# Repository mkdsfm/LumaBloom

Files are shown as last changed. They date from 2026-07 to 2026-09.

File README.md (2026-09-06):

# LumaBloom

Smart ambient-light sensor for Windows displays with ESP32-C6 and displayless ESP32-C3 Super Mini electronics variants for the same printable flower design.

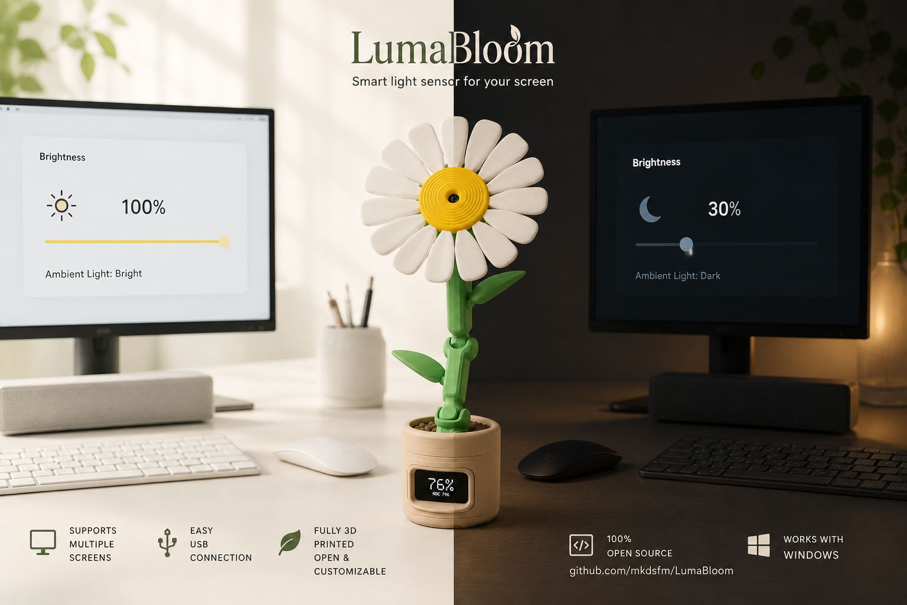
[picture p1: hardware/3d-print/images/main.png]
LumaBloom product preview


[Watch the demo video](https://youtu.be/8JuLW-chpVk?si=8Hq7ECl7L5f6ZxNs)

LumaBloom reads room light from a KY-018 sensor on a supported ESP32 board, streams raw JSON telemetry over USB, and lets the Windows companion app adjust monitor brightness automatically.

## Highlights

- ESP32-C6 firmware for Waveshare `ESP32-C6-LCD-1.47` with an ambient-light-driven pixel-art flower animation.
- Displayless ESP32-C3 Super Mini firmware for a compact `KY-018` USB sensor.
- Raw `ADC` telemetry on both hardware tracks, with normalization handled by the Windows app and, for display only, locally by the ESP32-C6 UI.
- Live Windows terminal dashboard for status, manual brightness, settings, events, and diagnostics.
- In-app firmware updates with automatic COM-port selection and a refreshed manual port dropdown.
- Shared printable flower enclosure with `.3mf` plates, STEP sources, STL exports, photos, and demo media; the ESP32-C3-specific lower pot is not available yet.
- User-tunable brightness curve, including anchoring the curve to the current room light, plus smoothing, hysteresis, gamma, language, and autostart settings.

## Project Map

| Path | Purpose |
| --- | --- |
| [`firmware/`](firmware/) | ESP-IDF firmware projects for ESP32-C6 and ESP32-C3 Super Mini |
| [`pc-app/`](pc-app/) | Windows-only .NET companion app |
| [`hardware/`](hardware/) | Wiring, BOM, assembly, printable enclosure, and hardware revisions |
| [`docs/`](docs/) | Protocol, settings, setup, firmware, and build docs |

## Documentation

| Start here | What it covers |
| --- | --- |
| [`docs/getting-started.md`](docs/getting-started.md) | End-to-end setup from device to Windows app |
| [`docs/firmware.md`](docs/firmware.md) | ESP32-C6 and ESP32-C3 firmware build, flash, monitor, and release notes |
| [`docs/build.md`](docs/build.md) | PC app restore, build, test, run, and publish commands |
| [`hardware/README.md`](hardware/README.md) | Hardware index, assembly, wiring, BOM, and enclosure assets |
| [`docs/protocol.md`](docs/protocol.md) | USB JSONL telemetry contract |
| [`docs/sensor-transports-and-monitor-ddc.md`](docs/sensor-transports-and-monitor-ddc.md) | Sensor transport and monitor DDC/CI brightness control docs, with English and Russian variants |
| [`docs/device-profiles.md`](docs/device-profiles.md) | Single-device runtime defaults and settings model |
| [`CONTRIBUTING.md`](CONTRIBUTING.md) | Contribution workflow and validation expectations |

## How It Works

1. The ESP32 board reads the KY-018 sensor; the ESP32-C6 build also visualizes ambient light on its onboard LCD.
2. The Windows app discovers the device over a COM port.
3. The device streams raw light telemetry over USB.
4. The app maps ambient light to monitor brightness using the active settings, response curve, and smoothing settings.
5. On the ESP32-C6 track, the LCD shows a local normalized percentage derived from the configured raw range; the ESP32-C3 track has no display.

Telemetry example:

```json
{"id":"lumabloom","ts":1234567,"raw":1840}
```

## Supported Targets

- Waveshare `ESP32-C6-LCD-1.47` or touch variant with onboard LCD: [`firmware/firmware_esp32c6/`](firmware/firmware_esp32c6/)
- `ESP32-C3 Super Mini` with built-in USB Serial/JTAG and no display: [`firmware/firmware_esp32c3_supermini/`](firmware/firmware_esp32c3_supermini/)
- Sensor: KY-018 analog light sensor on either track
- Desktop app: Windows 10/11
- Firmware: ESP-IDF
- App runtime: .NET SDK 10.0+

## License

Repository code and documentation use the root repository license.

Custom physical enclosure assets in [`hardware/3d-print/`](hardware/3d-print/) are licensed separately under `CC BY-NC 4.0`; see [`hardware/3d-print/LICENSE.md`](hardware/3d-print/LICENSE.md).

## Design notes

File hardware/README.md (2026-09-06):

# Hardware

This section contains wiring and component notes for both supported boards plus assembly checks and the printable LumaBloom flower enclosure.

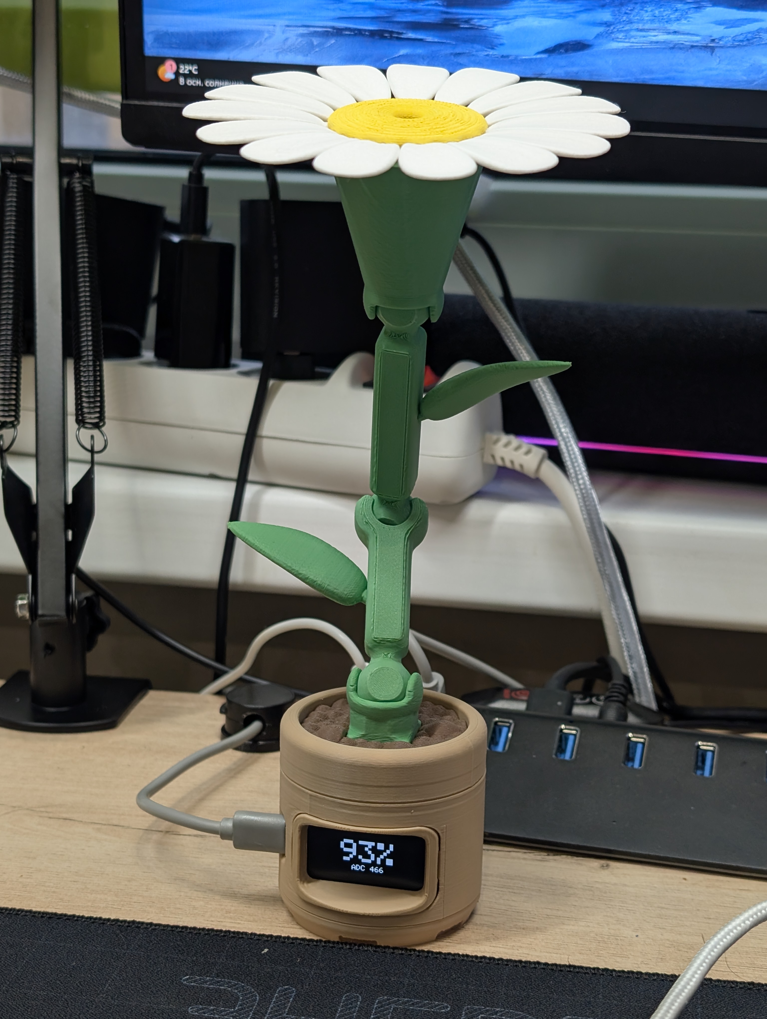
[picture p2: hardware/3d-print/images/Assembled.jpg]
Assembled LumaBloom device


## Sections

| Path | Purpose |
| --- | --- |
| [`WIRING.md`](WIRING.md) | KY-018 wiring for the ESP32-C6 and ESP32-C3 hardware tracks |
| [`BOM.md`](BOM.md) | Bill of materials for the current supported builds |
| [`ASSEMBLY.md`](ASSEMBLY.md) | Shared flower assembly, ESP32-C6 pot assembly, and smoke checks |
| [`REVISIONS.md`](REVISIONS.md) | Hardware revision log |
| [`3d-print/`](3d-print/) | Printable LumaBloom enclosure notes |
| [`3d-print/enclosure/`](3d-print/enclosure/) | Slicer-ready `.3mf` plates grouped by color |
| [`3d-print/images/`](3d-print/images/) | Product preview and per-color print reference images |
| [`3d-print/source/`](3d-print/source/) | STEP source models and selected STL exports |
| [`3d-print/LICENSE.md`](3d-print/LICENSE.md) | License notes for physical-design assets |

## Supported Hardware Track

### Waveshare ESP32-C6-LCD-1.47 + KY-018

- Board: Waveshare `ESP32-C6-LCD-1.47`.
- Sensor: KY-018 analog light sensor.
- Display: onboard ST7789 LCD.
- Firmware: ESP-IDF project in `firmware/firmware_esp32c6/`.
- Telemetry value: raw ADC reading over USB; normalized percent stays local to the device LCD and app processing.

### ESP32-C3 Super Mini + KY-018

- Board: ESP32-C3 Super Mini with built-in USB Serial/JTAG exposed on USB.
- Sensor: KY-018 analog light sensor on `GPIO4` (`ADC1_CH4`).
- Display: none.
- Firmware: ESP-IDF project in `firmware/firmware_esp32c3_supermini/`.
- Telemetry value: native 12-bit ADC reading over USB; normalization remains in `pc-app`.

## Notes

- The flower, sensor holder, stem, joints, petals, and leaves are shared by the ESP32-C6 and ESP32-C3 builds.
- The lower pot assembly depends on the board. The repository currently contains the ESP32-C6 pot; the ESP32-C3 Super Mini pot has not been modeled or published yet.
- A complete ESP32-C3 enclosure cannot be printed from the current files until its pot and board-mounting parts are added.
- Custom 3D-print enclosure assets are licensed under `CC BY-NC 4.0`; see [`3d-print/LICENSE.md`](3d-print/LICENSE.md).
- Do not use `GPIO0` for the KY-018 signal on ESP32-C6; it can interfere with normal startup.
- For PC application behavior, calibration, and telemetry details, see `docs/protocol.md` and `docs/device-profiles.md`.

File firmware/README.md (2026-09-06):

# Custom Firmware

You can implement compatible firmware for any board, microcontroller, sensor, or framework that can expose a serial port to the Windows application.

## Required Functionality

The firmware must:

- read the ambient-light sensor and provide its raw integer value;
- expose a serial connection at `115200 baud`;
- send one JSON object per line approximately every `200 ms`;
- terminate every message with `\n`;
- identify the protocol with `"id":"lumabloom"`;
- include an integer uptime timestamp in milliseconds in `ts`;
- include the raw sensor reading in `raw`;
- continue sending telemetry while the device is connected.

Example:

```json
{"id":"lumabloom","ts":1234567,"raw":1840}
```

## Sensor Value

`raw` must be a JSON integer that fits in a signed 32-bit value. Send the sensor value in its native, consistent scale; for example, ADC counts in `0..1023` or `0..4095`. Integer lux values are also usable. Do not convert the value to a percentage and do not assume that a specific ADC range is required.

The scale must have a consistent direction: apart from normal sensor noise, `raw` should generally increase or generally decrease as the room gets brighter. Either direction is supported because the Windows application can invert it. Values outside the configured range are clamped.

The current PC defaults are `adcMin=200`, `adcMax=3200`, and `invert=true`, matching the reference ESP32-C6 with KY-018. A firmware implementation for another sensor or board can use a different range.

## PC Processing And Configuration

The Windows application:

1. clamps `raw` to the configured `adcMin..adcMax` range and normalizes it to `0..1`;
2. reverses the normalized value when `invert=true`;
3. applies EMA smoothing and gamma correction;
4. maps the result through the configurable ambient-light-to-monitor-brightness curve;
5. applies brightness limits, hysteresis, and a maximum step size.

The sensor range, direction, smoothing, gamma, brightness curve, brightness limits, hysteresis, and maximum step are configurable in `pc-app` or `appsettings.json`. Therefore, firmware-side normalization, smoothing, calibration commands, and brightness calculation are not required. A display and buttons are also optional.

## Required Release Build Script

Every immediate firmware project directory under `firmware/` must contain its own `build_merged.py`. There is intentionally no shared firmware build implementation: each project owns its toolchain commands, board variants, flash layout, and merge process. The project script may call ESP-IDF, Arduino, PlatformIO, STM32 tools, vendor utilities, or any other required build system.

The script is the stable entrypoint used by release skills and must:

- accept `--tag <version>` and include that tag in every output filename;
- build every hardware/firmware variant supported by that project when no variant filter is supplied;
- create full-device flashable binaries under `build/release/`;
- name each artifact `*_<tag>_merged.bin`;
- delete old release binaries and manifests for the requested tag before creating new artifacts;
- create a `<binary>.manifest.json` sidecar for every merged binary;
- accept `--skip-build` to recreate merged files from existing valid build artifacts;
- accept `--dry-run` for command validation without changing build outputs;
- return a non-zero exit code if any supported variant fails, so a release cannot silently omit firmware.

The Python entrypoint is only a project-local adapter. It does not require the firmware itself to use Python or ESP tooling.

Each manifest uses schema version `1` and contains:

```json
{
  "schemaVersion": 1,
  "version": "2.1.0",
  "fileName": "example_2.1.0_merged.bin",
  "variant": "board-variant",
  "board": "board-id",
  "flashMethod": "vendor-tool",
  "chip": "chip-id",
  "baudRate": 460800,
  "offset": "0x0"
}
```

The Windows app currently accepts only manifests with `flashMethod` set to `esptool`. Other projects still publish their binaries and manifests, but require a matching PC-side flasher before they can be selected in the app.

To build release binaries manually, run every project's script. Release skills discover these entrypoints automatically and fail if a firmware directory does not provide one.

## Documentation

- [`docs/protocol.md`](../docs/protocol.md) — required serial transport and telemetry contract.
- [`docs/sensor-transports-and-monitor-ddc.md`](../docs/sensor-transports-and-monitor-ddc.md) — end-to-end sensor transport and monitor-control architecture.
- [`firmware_esp32c6/README.md`](firmware_esp32c6/README.md) — ESP32-C6 LCD reference implementation.
- [`firmware_esp32c3_supermini/README.md`](firmware_esp32c3_supermini/README.md) — displayless ESP32-C3 Super Mini reference implementation.

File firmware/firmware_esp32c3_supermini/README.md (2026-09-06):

# brightness_sensor_esp32c3_supermini

ESP-IDF firmware for an `ESP32-C3 Super Mini` with a `KY-018` analog light sensor and no display.

The firmware reads the native 12-bit ADC value every `200 ms` and sends the existing LumaBloom JSONL telemetry over the ESP32-C3 built-in USB Serial/JTAG console:

```json
{"id":"lumabloom","ts":1234567,"raw":1840}
```

Normalization, smoothing, curve mapping, and monitor brightness control remain in `pc-app`.

## Supported Hardware

This project targets Super Mini boards whose USB connector is wired to the ESP32-C3 built-in USB Serial/JTAG controller.

| KY-018 | ESP32-C3 Super Mini |
| --- | --- |
| `VCC` / `+` | `3V3` |
| `GND` / `-` | `GND` |
| `AO` / `S` | `GPIO4` (`ADC1_CH4`) |

Use only the analog output and do not power the KY-018 from `5V`. GPIO18 and GPIO19 are reserved for USB D- and D+.

## Build And Flash

Use an ESP-IDF 6.x PowerShell:

```powershell
cd firmware\firmware_esp32c3_supermini
idf.py set-target esp32c3
idf.py build
idf.py -p COM5 flash monitor
```

Replace `COM5` with the board's port. Close `pc-app` and other serial monitors before flashing if the port is busy.

The USB console is selected in `sdkconfig.defaults`. The project does not use light sleep or deep sleep because either can remove the USB serial device.

## Release Binary

Create the full-device merged binary and manifest:

```powershell
python build_merged.py --tag 2.1.0
```

Outputs:

```text
build/release/luma_bloom_esp32c3-supermini_2.1.0_merged.bin
build/release/luma_bloom_esp32c3-supermini_2.1.0_merged.bin.manifest.json
```

Flash the merged binary at offset `0x0`:

```powershell
esptool.py --chip esp32c3 --port COM5 --baud 460800 write-flash 0x0 build\release\luma_bloom_esp32c3-supermini_2.1.0_merged.bin
```

The build adapter also supports `--list`, `--variant esp32c3-supermini`, `--skip-build`, and `--dry-run`.

## PC App Settings

The current built-in baseline (`adcMin=200`, `adcMax=3200`, `invert=true`) is a starting point. KY-018 modules and mounting conditions vary, so observe `raw` in bright and dark conditions and tune `processing.adcMin`, `processing.adcMax`, and `processing.invert` through the app or `appsettings.json`.

No firmware calibration command is required.

## Expected Runtime Behavior

- startup logs identify the ESP32-C3 Super Mini target and GPIO4 sensor input;
- every successful read produces one JSON line;
- ADC errors are logged and never produce invented telemetry;
- after a read failure the ADC handle is released and initialization is retried on the next cycle;
- no display, buttons, Wi-Fi, Bluetooth, or serial command task is started.

## Troubleshooting

- If no COM port appears, confirm that the board exposes built-in USB Serial/JTAG rather than only an unrelated USB-UART bridge.
- If the firmware was configured in a way that disables USB, hold `BOOT` (GPIO9 low), reset the board, and flash a corrected build.
- If `raw` does not react, verify `AO/S -> GPIO4`, `3V3`, common `GND`, and short reliable wiring.
- If flashing reports a busy port, close the Windows app and all serial terminals.

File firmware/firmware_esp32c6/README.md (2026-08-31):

# brightness_sensor_esp32c6

`ESP-IDF` firmware for the `Waveshare ESP32-C6-LCD-1.47` board.

The project supports multiple LCD configurations, including `ST7789` and
`JD9853` based displays. `ST7789` is the default build target, while the
`JD9853` version can be selected explicitly during compilation.

## What the Firmware Does

-   drives the built-in `1.47"` LCD using the selected board/display
    configuration;
-   reads the raw `ADC` value from a `KY-018` photoresistor module;
-   shows a full-screen animated pixel-art flower plus percentage and
    ADC overlays on the horizontal LCD;
-   exchanges JSONL messages with `pc-app` over `USB Serial`;
-   stays compatible with the Windows application in `pc-app/`.

Telemetry format:

`{"id":"lumabloom","ts":123456,"raw":1840}`

For this firmware, `raw` is the only measurement field sent over USB.
The built-in LCD always shows the current ambient percentage plus the
current `ADC` line. That normalized percentage is derived locally from
the configured raw range and is not mirrored into telemetry.

The Windows application performs normalization, smoothing, curve mapping,
and user calibration from `raw`; no calibration command is required from
the firmware.

## LCD UI

The LCD uses a nine-frame palette-indexed sprite animation. The flower
opens as the displayed ambient-light percentage rises and closes as it
falls.

The raw sensor percentage is used as the target value. The displayed
percentage approaches that target progressively instead of jumping
immediately. Larger differences use larger steps, while movement slows
near the target.

The displayed percentage drives:

-   the numeric percentage;
-   the software-rendered progress bar;
-   the target flower animation frame.

Relevant files:

-   `main/ui_screen.c` - the complete screen renderer and UI state
    update entrypoint
-   `main/display_lcd.c` - low-level LCD primitives and pixel font
    rendering
-   `main/app_config.h` - default board selection and board-specific LCD
    configuration
-   `assets/flower_animation.png` - master sprite sheet with nine
    vertical `160x86` frames
-   `main/flower_sprite_asset.c` - generated indexed frames and
    display-specific RGB565/BGR565 palettes
-   `tools/convert_flower_sprite.py` - deterministic standard-library
    asset converter
-   `tools/README.md` - sprite converter usage

Current screen behavior:

-   each `160x86` source frame is expanded to `320x172` with crisp
    nearest-neighbor 2x pixels;
-   the flower advances toward the current light range one frame every
    `150 ms`;
-   frame boundaries use `2%` hysteresis;
-   percentage and `ADC ####` are drawn in the upper-left with a dark
    pixel outline;
-   startup shows `--%` and `ADC ----`; a read error after valid data
    shows `ERR` and `ADC ERR` while preserving the last frame.

The generated sprite asset contains palettes for both supported display
configurations. `ST7789` uses the BGR565 palette and `JD9853` uses the
RGB565 palette. The required palette is selected at compile time using
`APP_DISPLAY_TYPE`.

Runtime behavior:

-   the screen shows an ambient-light percentage derived from the raw
    `KY-018` range;
-   UI transitions are smoothed locally and do not change the raw
    telemetry value;
-   the raw ADC line keeps updating independently of any compatibility
    calibration command.

After editing the master PNG, regenerate the C asset once from this
directory:

``` powershell
python tools\convert_flower_sprite.py assets\flower_animation.png main\flower_sprite_asset.h main\flower_sprite_asset.c
```

The generated asset contains both display palettes, so `--display` is
not required and the converter does not need to be rerun when switching
between `ST7789` and `JD9853`.

See `tools/README.md` for converter details.

## Building the Firmware

### Default ST7789 Build

`ST7789` is the default board/display configuration.

Build normally:

``` powershell
idf.py build
```

The output is created in:

``` text
build/
```

### JD9853 Build

To build the `JD9853` version without changing the default
configuration:

``` powershell
idf.py -B build_touch -D APP_DISPLAY_TYPE=2 build
```

The output is created separately in:

``` text
build_touch/
```

This keeps the normal `ST7789` build in `build/` and the `JD9853` build
in `build_touch/`.

## Building and Flashing from ESP-IDF

### ST7789

Build and flash the default `ST7789` version:

``` powershell
cd firmware\firmware_esp32c6
idf.py set-target esp32c6
idf.py build
idf.py -p COM5 flash monitor
```

Replace `COM5` with the correct serial port.

### JD9853

Build the `JD9853` version into the separate `build_touch/` directory:

``` powershell
cd firmware\firmware_esp32c6
idf.py -B build_touch -D APP_DISPLAY_TYPE=2 build
```

Flash the `JD9853` build:

``` powershell
idf.py -B build_touch -D APP_DISPLAY_TYPE=2 -p COM5 flash monitor
```

Replace `COM5` with the correct serial port.

## Quick Flashing with a Prebuilt Binary

If you already have a merged binary, flashing a single file is the
simplest option.

Expected file name:

-   `brightness_sensor_esp32c6_merged.bin`

Flashing command:

``` powershell
esptool.py --chip esp32c6 --port COM5 --baud 460800 write-flash 0x0 brightness_sensor_esp32c6_merged.bin
```

Replace `COM5` with your port.

After flashing, reconnect the board or press `RST`.

## Building a Merged Binary from Sources

Use the project-owned release script from an ESP-IDF PowerShell. Without a variant filter it builds both supported board variants:

``` powershell
cd firmware\firmware_esp32c6
python build_merged.py --tag 2.1.0
```

The merged binaries are created here:

-   `build/release/luma_bloom_esp32c6-display_2.1.0_merged.bin`
-   `build/release/luma_bloom_esp32c6-touch_2.1.0_merged.bin`
-   one `<binary>.manifest.json` sidecar next to each merged binary

The script keeps release build trees under `build/variants/`, passes the correct `APP_DISPLAY_TYPE` and release tag as `PROJECT_VER` for each variant, and uses `esptool merge-bin` with ESP-IDF's generated `flash_args` for the final full-device images. `--skip-build` performs only this merge step and manifest generation from existing variant build trees. Use `--variant esp32c6-display` or `--variant esp32c6-touch` only for a targeted local build; release workflows run without a filter and therefore build both.

For the Codex skill workflow that builds every firmware project and can flash one explicitly selected ESP binary, see
[../../docs/skills-for-users.md](../../docs/skills-for-users.md).

## Flashing Separate `.bin` Files

### ST7789

After the default `idf.py build`, the standard artifacts are:

-   `build/bootloader/bootloader.bin`
-   `build/partition_table/partition-table.bin`
-   `build/brightness_sensor_esp32c6.bin`

Flash them with:

``` powershell
esptool.py --chip esp32c6 --port COM5 --baud 460800 write-flash --flash-mode dio --flash-freq 80m --flash-size 2MB 0x0 build\bootloader\bootloader.bin 0x8000 build\partition_table\partition-table.bin 0x10000 build\brightness_sensor_esp32c6.bin
```

### JD9853

After:

``` powershell
idf.py -B build_touch -D APP_DISPLAY_TYPE=2 build
```

the corresponding artifacts are:

-   `build_touch/bootloader/bootloader.bin`
-   `build_touch/partition_table/partition-table.bin`
-   `build_touch/brightness_sensor_esp32c6.bin`

Flash them with:

``` powershell
esptool.py --chip esp32c6 --port COM5 --baud 460800 write-flash --flash-mode dio --flash-freq 80m --flash-size 2MB 0x0 build_touch\bootloader\bootloader.bin 0x8000 build_touch\partition_table\partition-table.bin 0x10000 build_touch\brightness_sensor_esp32c6.bin
```

Replace `COM5` with the correct serial port.

## Hardware Wiring

### Onboard LCD

LCD pins, controller type, offsets, orientation, colors, and related
hardware parameters are selected through:

-   `main/app_config.h`

Supported display configurations:

-   `ST7789` - default non-touch configuration (`APP_DISPLAY_TYPE=1`), with
    hardware color inversion enabled
-   `JD9853` - optional touch configuration (`APP_DISPLAY_TYPE=2`), with
    hardware color inversion disabled

When `APP_DISPLAY_TYPE` is not explicitly defined, the firmware uses
`ST7789`.

Keep board-specific GPIO and panel settings in the corresponding
configuration profile rather than hard-coding them in UI code.

### KY-018

Default wiring:

-   `VCC` -\> `3V3`
-   `GND` -\> `GND`
-   `AO` -\> `GPIO4`

Important:

-   only the analog output `AO` is used;
-   a common `GND` is required;
-   do not supply `5V` to the sensor;
-   for `ESP32-C6`, do not use `GPIO0` as the main `KY-018` pin because
    it may interfere with normal board startup.

If the sensor does not provide valid readings:

-   check that `AO` is connected specifically to `GPIO4`;
-   check `3V3` power and common `GND`;
-   check the contact quality on the breadboard;
-   if the module is labeled `S`, `+`, `-`, then `S` is the analog
    signal (`AO`).

## Expected Behavior After Startup

On the screen:

-   a numeric ambient-light percentage
-   `ADC ####`

In the monitor:

-   `ESP-IDF` startup logs;
-   the message `LCD ready`;
-   after successful sensor initialization, a line similar to:

`KY-018 ready on ADC unit 1, channel 4, gpio=4`

If initialization or reading fails, the firmware logs
`sensor_ky018_* failed`.

## Connecting to the Windows Application

For `pc-app`, use this example:

-   `pc-app/appsettings.esp32c6.example.json`

Important:

-   telemetry must keep `id="lumabloom"` so `pc-app` recognizes the
    device as compatible;
-   `baudRate` must be `115200`;
-   `pc-app` can use telemetry immediately from the raw sensor field
    without startup calibration.

## Project Settings

The main constants are defined in:

-   `main/app_config.h`

You can change:

-   `APP_PROTOCOL_ID`
-   `APP_DISPLAY_TYPE`
-   refresh intervals
-   `APP_KY018_ADC_CHANNEL`
-   `APP_KY018_ADC_GPIO`
-   `APP_KY018_ADC_MIN`
-   `APP_KY018_ADC_MAX`
-   `APP_KY018_GAMMA`
-   LCD pins and dimensions

Display type values:

-   `APP_DISPLAY_ST7789 = 1`
-   `APP_DISPLAY_JD9853 = 2`

If `APP_DISPLAY_TYPE` is not supplied by the build system, `ST7789` is
used by default.

Current defaults for the built-in KY-018 path are tuned to a practical
raw range on the ESP32-C6 board:

-   `APP_KY018_ADC_MIN=200`
-   `APP_KY018_ADC_MAX=3200`
-   `APP_KY018_INVERT=1`
-   `APP_KY018_GAMMA=2.0f`

If you change `APP_PROTOCOL_ID`, update the `pc-app` protocol
expectation to match; the current desktop app expects `lumabloom`.

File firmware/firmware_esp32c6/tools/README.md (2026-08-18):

# Flower Sprite Converter

Converts the flower sprite sheet into C assets used by the ESP32
firmware.

The generated asset contains color palettes for both supported displays.
The correct palette is selected at compile time using
`APP_DISPLAY_TYPE`.

## Usage

Run from the `firmware_esp32c6` directory:

``` powershell
python tools\convert_flower_sprite.py <source> <header> <implementation>
```

Parameters:

-   `<source>` --- source RGBA PNG (`160x774`, 9 frames of `160x86`)
-   `<header>` --- output `.h` file
-   `<implementation>` --- output `.c` file

Example:

``` powershell
python tools\convert_flower_sprite.py assets\flower_animation.png main\flower_sprite_asset.h main\flower_sprite_asset.c
```

The converter generates:

-   BGR565 palette for ST7789
-   RGB565 palette for JD9853
-   shared indexed sprite frames for both displays

The required palette is selected automatically during firmware
compilation.

ST7789 is the default firmware target. To build the default version:

``` powershell
idf.py build
```

To build the JD9853 version into a separate directory:

``` powershell
idf.py -B build_jd9853 -D APP_DISPLAY_TYPE=2 build
```

Generated `.c/.h` files should not be edited manually.

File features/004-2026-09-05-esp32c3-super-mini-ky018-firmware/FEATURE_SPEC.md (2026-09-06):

# Спецификация: прошивка ESP32-C3 Super Mini + KY-018 без дисплея

## Краткое описание

Добавить в LumaBloom второй аппаратный трек: отдельную ESP-IDF-прошивку для платы `ESP32-C3 Super Mini` с аналоговым датчиком освещённости `KY-018`, без дисплея, кнопок и локального UI.

Устройство считывает исходное значение ADC и приблизительно каждые `200 ms` передаёт его по USB Serial в существующем JSONL-формате LumaBloom. Текущий Windows-клиент должен обнаруживать устройство и обрабатывать его телеметрию без изменения wire-протокола и кода `pc-app`.

## Проблема

В репозитории есть только полнофункциональная прошивка для Waveshare ESP32-C6 с LCD. Для компактной и дешёвой сборки без экрана отсутствует поддерживаемый firmware-проект, документированная распиновка, проверяемая процедура сборки и совместимый release-артефакт.

## Пользователи и цели

Основной пользователь — владелец Windows-компьютера, которому нужен компактный USB-датчик освещённости без дисплея.

Цели:

- поддержать `ESP32-C3 Super Mini + KY-018` как отдельный аппаратный трек;
- сохранить текущий протокол и автоматическое обнаружение в `pc-app`;
- обеспечить повторяемые build, flash и release-сценарии ESP-IDF;
- явно задокументировать подключение датчика, общие детали цветка и отсутствие отдельного нижнего горшка для ESP32-C3.

## Сценарии

### Первичная прошивка

1. Пользователь подключает KY-018 к `3V3`, `GND` и `GPIO4` платы ESP32-C3 Super Mini.
2. Собирает проект с target `esp32c3` и прошивает плату через её USB-порт.
3. После перезапуска устройство появляется в Windows как COM-порт и начинает публиковать телеметрию.

### Работа с Windows-приложением

1. `pc-app` перебирает доступные COM-порты на скорости `115200`.
2. Получает валидную строку `{"id":"lumabloom","ts":1234567,"raw":1840}`.
3. Выбирает порт и использует `raw` с текущими настройками нормализации, сглаживания и кривой яркости.

### Ошибка датчика

1. Инициализация или чтение ADC завершается ошибкой.
2. Прошивка записывает диагностическое сообщение в лог и не публикует вымышленное значение `raw`.
3. Через очередной интервал прошивка повторяет инициализацию и после восстановления автоматически возобновляет валидную телеметрию.

## Функциональные требования

### FR-1. Отдельный firmware-проект

В `firmware/firmware_esp32c3_supermini/` должен находиться самостоятельный ESP-IDF-проект с target `esp32c3`. Он не должен включать LCD-драйверы, графические assets, display task, кнопки или зависимости от прошивки ESP32-C6 во время сборки.

### FR-2. Поддерживаемая аппаратная конфигурация

Базовая распиновка:

| KY-018 | ESP32-C3 Super Mini |
| --- | --- |
| `VCC` / `+` | `3V3` |
| `GND` / `-` | `GND` |
| `AO` / `S` | `GPIO4` (`ADC1_CH4`) |

Используется только аналоговый выход. Питание датчика от `5V` не поддерживается. `GPIO18` и `GPIO19`, занятые встроенным USB Serial/JTAG, не должны переназначаться.

### FR-3. Считывание датчика

Прошивка должна использовать ESP-IDF ADC oneshot driver, `ADC_UNIT_1`, `ADC_CHANNEL_4`, разрядность `12 bit` и attenuation `12 dB`. В telemetry передаётся непосредственный целочисленный результат ADC без firmware-side нормализации, гаммы, EMA, усреднения или пересчёта в проценты.

### FR-4. Частота и время

После запуска прошивка должна пытаться получить новое показание приблизительно каждые `200 ms`. Поле `ts` содержит целое неотрицательное число миллисекунд с момента запуска устройства и не обязано сохраняться после перезапуска.

### FR-5. Wire-протокол

Каждое успешное чтение должно формировать ровно одну строку UTF-8/ASCII JSON:

```json
{"id":"lumabloom","ts":1234567,"raw":1840}
```

Строка завершается `\n`. Нормативные поля:

- `id` — строка `lumabloom`;
- `ts` — uptime в миллисекундах;
- `raw` — знаковое 32-битное целое с исходным результатом ADC.

Новые обязательные поля и сообщения состояния в wire-контракт не добавляются. Логи ESP-IDF могут находиться в том же serial-потоке: `pc-app` уже игнорирует строки, не являющиеся поддерживаемой телеметрией.

### FR-6. USB Serial

Основной транспорт — встроенный USB Serial/JTAG ESP32-C3, выведенный на USB-разъём поддерживаемой платы. Консоль ESP-IDF должна быть направлена в `CONFIG_ESP_CONSOLE_USB_SERIAL_JTAG`; UART console и light/deep sleep не используются. Логическая скорость соединения для `pc-app` остаётся `115200 baud`.

### FR-7. Ошибки и восстановление

При ошибке инициализации или чтения ADC прошивка должна:

- записать причину через ESP-IDF logging;
- не отправлять telemetry-объект с ошибочным, предыдущим или подставным `raw`;
- пометить sensor handle как требующий повторной инициализации;
- повторить инициализацию на следующем цикле без перезапуска устройства.

Ошибка записи в serial не должна останавливать цикл чтения. После восстановления соединения или датчика публикация продолжается автоматически.

### FR-8. Совместимость с `pc-app`

Текущие `SensorMessageParser`, `SerialPortDiscovery` и обработка `raw` не меняются. ESP32-C3 использует общий встроенный baseline приложения (`adcMin=200`, `adcMax=3200`, `invert=true`) как стартовые настройки; пользователь может скорректировать диапазон и направление через UI или `appsettings.json` по фактическим показаниям своего экземпляра KY-018.

Firmware-side команда калибровки и ответы `calibrationResult` не требуются.

### FR-9. Сборка и прошивка

Проект должен собираться ESP-IDF 6.x командами:

```powershell
idf.py set-target esp32c3
idf.py build
idf.py -p COM5 flash monitor
```

`sdkconfig` остаётся локальным generated-файлом; воспроизводимые настройки target и USB console хранятся в `sdkconfig.defaults`.

### FR-10. Release-артефакт

Проект должен иметь обязательный `build_merged.py`, соответствующий контракту `firmware/README.md`. Для единственного варианта `esp32c3-supermini` скрипт создаёт:

```text
build/release/luma_bloom_esp32c3-supermini_<tag>_merged.bin
build/release/luma_bloom_esp32c3-supermini_<tag>_merged.bin.manifest.json
```

Manifest schema v1 содержит `variant="esp32c3-supermini"`, `board="esp32-c3-super-mini"`, `flashMethod="esptool"`, `chip="esp32c3"`, `baudRate=460800` и `offset="0x0"`. Артефакт должен прошиваться как full-device image и автоматически подхватываться существующими release skills и экраном `Update`.

### FR-11. Документация

Документация должна описывать новый hardware track, распиновку, требования USB, build/flash/release-команды, ожидаемую телеметрию и настройку фактического ADC-диапазона. Общая часть печатного цветка должна быть описана как одинаковая для ESP32-C6 и ESP32-C3, а существующий нижний горшок и крепление платы — как C6-специфичные. Отдельная модель горшка для ESP32-C3 пока отсутствует.

## Нефункциональные требования

- Прошивка после старта работает непрерывно и не требует пользовательского ввода.
- В steady state не создаются динамические ресурсы на каждый sensor cycle.
- Отсутствие дисплея не должно оставлять неиспользуемые UI-задачи или графические зависимости.
- Идентификатор протокола, период публикации и JSON-формат определяются в одном конфигурационном/владельческом месте, а не дублируются по модулям.
- Изменение не должно ухудшать сборку, release-артефакты или документацию ESP32-C6.

## Совместимость и миграция

- Wire-протокол остаётся без изменений; миграция `pc-app` и пользовательских настроек не требуется.
- Новый firmware-проект сосуществует с `firmware/firmware_esp32c6/`; существующий код ESP32-C6 не переносится и не удаляется.
- Portable release получает дополнительную пару `.bin` + manifest через существующее обнаружение firmware-проектов.
- Для платы с USB-UART bridge вместо выведенного встроенного USB Serial/JTAG данная конфигурация не гарантируется; такой вариант платы находится вне заявленного hardware target.

## Вне scope

- дисплей, LED-индикация, кнопки, Wi-Fi, Bluetooth, web UI и OTA;
- firmware-side нормализация, калибровка, сглаживание или управление яркостью монитора;
- изменение JSONL-протокола или `pc-app`;
- новый runtime device profile и автоматическое определение отдельных ADC-границ для C3;
- разработка нового нижнего горшка, крепления платы или иных 3D-моделей специально для ESP32-C3 Super Mini;
- поддержка цифрового выхода или иных датчиков;
- поддержка неизвестных ревизий Super Mini, чей USB-разъём не подключён к встроенному USB Serial/JTAG ESP32-C3.

## Измеримые результаты

- чистая ESP-IDF-сборка для target `esp32c3` завершается успешно;
- подключённая плата выдаёт валидную LumaBloom-телеметрию с периодом около `200 ms`;
- `pc-app` обнаруживает её без программных изменений;
- изменение освещения устойчиво изменяет `raw`, а после настройки диапазона меняет целевую яркость;
- release-скрипт формирует прошиваемый merged binary и валидный manifest.

## Допущения

- Целевая ESP32-C3 Super Mini имеет USB-разъём, подключённый к встроенному USB Serial/JTAG контроллеру ESP32-C3.
- На целевой плате выведены `3V3`, `GND` и `GPIO4`.
- KY-018 работает от `3.3V`, а его `S`/`AO` является аналоговым выходом.
- Точный полезный диапазон конкретного датчика зависит от экземпляра и условий установки, поэтому не становится новым жёстким firmware-контрактом.

## Источники аппаратных ограничений

- [ESP32-C3 Series Datasheet](https://documentation.espressif.com/esp32-c3_datasheet_en.html) — ADC pin mapping и USB pins.
- [USB Serial/JTAG Controller Console](https://docs.espressif.com/projects/esp-idf/en/latest/esp32c3/api-guides/usb-serial-jtag-console.html) — console configuration, flash и ограничения sleep/pin reuse.
- [ADC Oneshot Mode Driver](https://docs.espressif.com/projects/esp-idf/en/stable/esp32c3/api-reference/peripherals/adc_oneshot.html) — ADC oneshot lifecycle и ограничение ADC2 на ESP32-C3.

## Открытые вопросы

Нет. Аппаратная граница, распиновка, протокол и интеграция следуют существующему ESP-IDF-треку и общему firmware-контракту репозитория.

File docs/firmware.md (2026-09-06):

# Firmware

The repository contains two ESP-IDF 6.x firmware projects using the same LumaBloom JSONL protocol:

- `firmware/firmware_esp32c6/` for Waveshare ESP32-C6 1.47-inch LCD boards;
- `firmware/firmware_esp32c3_supermini/` for an ESP32-C3 Super Mini with no display.

Both read a KY-018 on GPIO4 and send its native ADC value to `pc-app`.

## Requirements

- ESP-IDF 6.x.
- A Waveshare `ESP32-C6-LCD-1.47` (`ST7789`), `ESP32-C6-Touch-LCD-1.47` (`JD9853`), or ESP32-C3 Super Mini whose USB connector exposes built-in USB Serial/JTAG.
- A KY-018 connected to `3V3`, `GND`, and `GPIO4` (`AO`/`S`) by default.

Do not power the KY-018 from `5V`. On ESP32-C6, do not use `GPIO0` for its analog signal because it can interfere with startup. On ESP32-C3, keep GPIO18 and GPIO19 reserved for USB.

## ESP32-C3 Super Mini

Run from `firmware/firmware_esp32c3_supermini/`:

```powershell
idf.py set-target esp32c3
idf.py build
idf.py -p COM5 flash monitor
```

The firmware has one sensor task and no LCD, UI, buttons, calibration command, Wi-Fi, or Bluetooth. It uses `ADC1_CH4` on GPIO4, sends one raw reading approximately every `200 ms`, and retries ADC initialization after failures.

Create a merged release binary with:

```powershell
python build_merged.py --tag 2.1.0
```

This produces `build/release/luma_bloom_esp32c3-supermini_2.1.0_merged.bin` plus its manifest. See the project-specific [`README.md`](../firmware/firmware_esp32c3_supermini/README.md) for details.

## ESP32-C6 Display Variants

`APP_DISPLAY_TYPE` selects the board/display pin profile and matching sprite palette:

| Value | Display | Build directory | Panel color inversion | Notes |
| --- | --- | --- | --- | --- |
| `1` | `ST7789` | `build/` | Enabled | Source-level default when no override is supplied |
| `2` | `JD9853` | `build_touch/` | Disabled | Selected explicitly with `-D APP_DISPLAY_TYPE=2` |

Keep the variants in separate build directories so configuring one does not overwrite the other.

## ESP32-C6 Build And Flash

Run commands from `firmware/firmware_esp32c6/` in an ESP-IDF PowerShell.

### ST7789

```powershell
idf.py set-target esp32c6
idf.py build
idf.py -p COM5 flash monitor
```

### JD9853

```powershell
idf.py -B build_touch -D APP_DISPLAY_TYPE=2 build
idf.py -B build_touch -D APP_DISPLAY_TYPE=2 -p COM5 flash monitor
```

Replace `COM5` with the board's COM port. Close `pc-app` and other serial monitors before flashing if the port is busy.

## Flash A Prebuilt Merged Binary

A merged image is written at offset `0x0`:

```powershell
esptool.py --chip esp32c6 --port COM5 --baud 460800 write-flash 0x0 brightness_sensor_esp32c6_merged.bin
```

Reconnect the board or press `RST` after flashing.

## Configuration

The main source-level settings are in:

```text
firmware/firmware_esp32c6/main/app_config.h
```

Important settings include:

- `APP_PROTOCOL_ID` (`lumabloom`); changing it breaks discovery by the current `pc-app` unless the app expectation is changed too.
- `APP_DISPLAY_TYPE`; selects the display profile.
- `APP_READ_INTERVAL_MS` (`200 ms`); controls sensor reads and telemetry publication.
- `APP_DISPLAY_INTERVAL_MS` (`50 ms`); controls UI task updates.
- `APP_ANIMATION_FRAME_INTERVAL_MS` (`150 ms`) and `APP_ANIMATION_HYSTERESIS_PERCENT` (`2%`).
- `APP_KY018_ADC_CHANNEL` and `APP_KY018_ADC_GPIO`; change both when moving the analog signal to another supported ADC pin.
- LCD pins, geometry, orientation, colors, and backlight settings for each display profile.

The non-touch `ST7789` panel requires hardware color inversion (`APP_LCD_INVERT_COLOR=true`) for the intended palette. The touch `JD9853` profile keeps panel color inversion disabled.

Current KY-018 normalization defaults are:

- `APP_KY018_ADC_MIN 200`
- `APP_KY018_ADC_MAX 3200`
- `APP_KY018_INVERT 1`
- `APP_KY018_GAMMA 2.0f`

With inversion enabled, a raw reading near `200` is the bright endpoint and one near `3200` is the dark endpoint.

## Runtime Behavior

The firmware runs independent sensor, serial-command, and display tasks:

- the sensor is sampled every `200 ms`;
- valid raw readings are published immediately as JSONL over USB Serial;
- sensor initialization is retried after failures;
- the LCD refreshes independently, so animation and percentage transitions remain smooth between sensor reads.

At startup the LCD shows `--%` and `ADC ----`. After valid data arrives it shows the locally normalized ambient percentage, a progress bar, `ADC ####`, and the animated flower. A later sensor error shows `ERR` and `ADC ERR` while preserving the last flower frame.

## Animated LCD

The `320x172` screen uses a nine-frame palette-indexed flower animation. Each `160x86` source frame is enlarged 2x with nearest-neighbor pixels. The displayed percentage approaches its target progressively; the flower then moves one frame every `150 ms`, with `2%` hysteresis around frame boundaries.

The master sprite sheet is:

```text
firmware/firmware_esp32c6/assets/flower_animation.png
```

It is an opaque `160x774` RGBA PNG containing nine vertical `160x86` frames. After editing it, regenerate the shared indexed frames and both display palettes from `firmware/firmware_esp32c6/`:

```powershell
python tools\convert_flower_sprite.py assets\flower_animation.png main\flower_sprite_asset.h main\flower_sprite_asset.c
```

The converter uses only the Python standard library and validates the image dimensions, opacity, and palette size. Do not edit the generated `flower_sprite_asset.h` or `flower_sprite_asset.c` manually.

## USB Serial Protocol

The firmware sends newline-delimited JSON (`JSONL`) telemetry over USB Serial at `115200 baud`.

Valid sensor readings produce raw telemetry only:

```json
{"id":"lumabloom","ts":1234567,"raw":1840}
```

The normalized percentage shown on the LCD is local UI state and is not sent to `pc-app`. The current desktop application performs all normalization, smoothing, curve mapping, and user calibration from the `raw` value.

See [`protocol.md`](protocol.md) for the desktop-facing telemetry contract.

## ESP32-C6 Release Binary

Create a merged binary for the default `ST7789` build:

```powershell
idf.py build
mkdir .\build\release -Force
idf.py merge-bin -f raw -o build\release\brightness_sensor_esp32c6_merged.bin
```

The result is written to:

```text
firmware/firmware_esp32c6/build/release/brightness_sensor_esp32c6_merged.bin
```

For a repeatable Codex build and optional flash workflow, see [`skills-for-users.md`](skills-for-users.md).

More implementation detail and separate-bin flashing commands are available in the firmware-specific [`README.md`](../firmware/firmware_esp32c6/README.md).

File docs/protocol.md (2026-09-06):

# Communication Protocol

The firmware sends newline-delimited JSON (`JSONL`) telemetry over USB Serial.

## Rate

- Send interval: `200 ms`
- Port speed: `115200 baud`

## Telemetry Format

`{"id":"lumabloom","ts":1234567,"raw":1840}`

## Telemetry Fields

- `id` (`string`) - protocol identifier; must be `lumabloom` for `pc-app` to treat the COM port as a compatible device
- `ts` (`number`) - milliseconds since device startup
- `raw` (`number`) - raw ADC reading used by `pc-app` for brightness processing, diagnostics, and curve anchoring

## `raw` Semantics

- For both `firmware/firmware_esp32c6/` and `firmware/firmware_esp32c3_supermini/`, `raw` is the only telemetry measurement field on the USB wire contract.
- The on-device LCD still derives a normalized ambient percent from the configured raw range, but that normalized display value is local to firmware UI and is not transmitted to `pc-app`.
- The ESP32-C3 Super Mini track has no display and sends the same native ADC field without firmware-side normalization.

## Message Separator

- Every message ends with a newline (`\n`)

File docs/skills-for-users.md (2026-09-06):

# Codex Skills for Users

This repo can be operated through Codex skills when you want repeatable build and flashing workflows without remembering every command.

## Recommended Skills

- `esp32-release-flash`
  Use this when you want Codex to run every firmware project's own merged-binary script and optionally flash one explicitly selected ESP artifact.
- `pc-app-portable-release`
  Use this when you want Codex to build every firmware project and the versioned Windows portable zip, including all matching merged binaries, their manifests, and `Tools/esptool.exe` for the in-app Update flow.
- `release-notes-github`
  Use this when you want Codex to draft or update GitHub release notes for this repo in English, and you can specify both the source tag and the target tag.
- `luma-bloom-release`
  Use this when you want Codex to coordinate the full release flow across firmware, Windows zip, and release notes, with an explicit source tag and target tag.

## Typical Requests

You can ask Codex things like:

- `use the esp32-release-flash skill to build all firmware files for tag 2.1.0`
- `use the esp32-release-flash skill to flash luma_bloom_esp32c6-touch_2.1.0_merged.bin to COM8`
- `use the esp32-release-flash skill to flash luma_bloom_esp32c3-supermini_2.1.0_merged.bin to COM8`
- `use the pc-app-portable-release skill to build the Windows zip for tag 0.3.0`
- `use the pc-app-portable-release skill to build the Windows zip for tag 0.3.0 with the firmware release folder bundled for the Update tab`
- `use the release-notes-github skill and write release notes; source tag: 0.2.1, target tag: 0.3.0`
- `use the luma-bloom-release skill; source tag: 0.2.1, target tag: 0.3.0; create release artifacts and write release notes`
- `use the luma-bloom-release skill; source tag: 0.2.1, target tag: 0.3.0; prepare the full release`

## What `esp32-release-flash` Does

The build skill:

- discovers every immediate project under `firmware/`;
- requires each project to provide its own `build_merged.py` adapter for its actual toolchain;
- builds every variant exposed by every project into that project's `build/release/` directory;
- currently creates both `esp32c6-display` and `esp32c6-touch` binaries for the ESP32-C6 project;
- creates the `esp32c3-supermini` binary for the displayless ESP32-C3 project;
- flashes one explicitly selected merged ESP binary to a chosen `COM` port;
- reuse existing artifacts with `--skip-build` when only reflashing is needed.

## User-Facing Workflow

1. Connect the ESP32 board over USB.
2. Ask Codex to use `esp32-release-flash`.
3. If you do not know the port, say so explicitly; Codex can probe available `COM` ports.
4. Wait for Codex to report:
   - all generated binary paths and filenames
   - whether flashing succeeded
5. After flashing, reopen the device or start `pc-app` if the board was reset.

## Recommended Wording

- For build only: `use the esp32-release-flash skill to create all firmware release bins for tag 2.1.0`
- For build and flash: `use the esp32-release-flash skill to build all firmware and flash <exact-file> to COM8`
- For reflashing an existing build: `use the esp32-release-flash skill to reflash the existing esp32c6 build without rebuilding`

## Notes

- Build logic is project-local and is not limited to ESP-IDF. New non-ESP firmware must provide the same `build_merged.py` entrypoint while implementing its own toolchain commands internally.
- When no tag is supplied, build skills use the MinVer version resolved for `pc-app`, normalized the same way as `AppVersion.Current`.
- Flashing may fail if the `COM` port is busy; in that case close `pc-app`, serial monitors, Arduino, PlatformIO, or any terminal attached to the port.
- The repo-local release-note skill lives in `.codex-skill-staging/release-notes-github/`.
- The repo-local Windows zip skill lives in `.codex-skill-staging/pc-app-portable-release/`.
- The repo-local orchestration skill lives in `.codex-skill-staging/luma-bloom-release/`.
- For these release skills, explicitly specify both the source tag and the target tag. Example: `source tag: 0.2.1, target tag: 0.3.0`.
- For the Windows portable artifact produced by these skills, include the target version in the zip filename, for example `luma-bloom-pc-app_0.3.0_win-x64-portable.zip`.
- For a reliable bundled firmware flasher, keep the official standalone Windows `esptool.exe` in `third_party/esptool/win-x64/esptool.exe` before building the portable zip.
- The portable `pc-app` release carries `BrightnessSensor.ConsoleApp.exe`, `Tools/esptool.exe`, and all target-tagged artifacts with their `<binary>.manifest.json` sidecars from `firmware/<project>/build/release/` inside `Firmware/` for the Update screen.

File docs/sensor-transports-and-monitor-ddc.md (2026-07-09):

# Reading Sensor Data over USB and Controlling Monitor Brightness

- [English](sensor-transports-and-monitor-ddc.md)
- [Русский](sensor-transports-and-monitor-ddc.ru.md)

This document explains two practical parts of the current system:

1. how sensor readings are read and interpreted over `USB`;
2. how computed brightness is sent to the monitor through `DDC/CI`, and how to check whether the monitor supports it.

## Current State

This repository currently implements:

- sensor telemetry over `USB Serial`;
- newline-delimited `JSON` messages such as `{"id":"lumabloom","ts":1234567,"raw":1840}`;
- `raw` as the only sensor value used by the desktop brightness pipeline;
- monitor brightness control in `Windows` through:
  - `WMI` for built-in displays;
  - `DDC/CI` for external monitors.

This repository does not currently implement:

- direct monitor control from `ESP32-C6` firmware over physical `I2C`.

Important: in this project, `DDC/CI` is used from the Windows side through monitor APIs. That is different from directly driving monitor `I2C` lines from `ESP32`.

## 1. Reading and Interpreting Sensor Values

## 1.1. Source of Truth

For the current `ESP32-C6` device, the source of truth is the `raw` field in telemetry:

```json
{"id":"lumabloom","ts":1234567,"raw":1840}
```

Where:

- `id` must be `lumabloom`;
- `ts` is milliseconds since device startup;
- `raw` is the raw `ADC` reading.

`raw` is currently the only measurement used by `pc-app` to compute brightness.

## 1.2. Transport in the Current Project

### `USB`

In the current project, `USB` is the main transport between the device and `pc-app`.

In practice this means:

- the device appears in Windows as a `COM` port;
- `pc-app` scans available `COM` ports;
- the first matching port is the one that emits valid JSONL messages with `id="lumabloom"` and a `raw` field.

Current wire-contract parameters:

- speed: `115200 baud`;
- message separator: `\n`;
- format: one JSON object per line;
- typical send interval: about `500 ms`.

The current `USB Serial` wire contract behaves like a sequential text stream:

- there is a byte stream;
- messages are framed by `\n`;
- each completed line must be a standalone JSON message.

## 1.3. Validating an Incoming Message

A message is usable only if all of the following are true:

- the line was fully read up to `\n`;
- the line is valid `JSON`;
- the root element is an object;
- there is a string field `id`;
- `id == "lumabloom"`;
- there is a numeric field `ts`;
- there is a numeric field `raw`.

If any of these checks fails, the message must not be used for brightness computation.

## 1.4. Interpreting `raw`

In the current implementation, `raw` is processed with these working values:

- `adcMin = 200`
- `adcMax = 3200`
- `invert = true`

In user configuration, the same parameters are exposed as:

- `processing.adcMin`
- `processing.adcMax`
- `processing.invert`

Current built-in defaults in `pc-app`:

- `processing.adcMin = 200`
- `processing.adcMax = 3200`
- `processing.invert = true`

This means:

- `200` is the lower bound of the working range and, in the current wiring, corresponds to the brightest scene;
- `3200` is the upper bound of the working range and, in the current wiring, corresponds to the darkest scene;
- if `raw` goes below `200`, the application still treats it as `200`;
- if `raw` goes above `3200`, the application still treats it as `3200`;
- after normalization, the value is inverted because in the current wiring more ambient light produces a lower `raw`.

### How the Parameters Affect Interpretation

#### `processing.adcMin`

This is the lower bound of the working range.

If `raw < adcMin`, the application treats the value as `adcMin`.

Practical effect:

- a smaller `adcMin` expands the usable range downward;
- a larger `adcMin` makes the system reach the "bright enough" region earlier;
- if `adcMin` is too large, part of the useful bright-light range gets compressed.

#### `processing.adcMax`

This is the upper bound of the working range.

If `raw > adcMax`, the application treats the value as `adcMax`.

Practical effect:

- a larger `adcMax` expands the usable range upward;
- a smaller `adcMax` makes the system reach the "dark enough" region earlier;
- if `adcMax` is too small, different dark scenes may start looking almost identical to the algorithm.

#### `processing.invert`

This flag defines how the direction of `raw` growth is interpreted.

If:

```text
invert = false
```

then a larger `raw` means more light after normalization.

If:

```text
invert = true
```

then after normalization the following is applied:

```text
normalized = 1.0 - normalized
```

and more ambient light corresponds to a smaller `raw`.

For the current `KY-018` wiring, the project uses:

```text
invert = true
```

### Conversion Formula

First, the input value is clamped to the working range:

```text
clamped = clamp(raw, adcMin, adcMax)
```

Then it is normalized:

```text
normalized = (clamped - adcMin) / (adcMax - adcMin)
```

If `invert = true`, one more step is applied:

```text
normalized = 1.0 - normalized
```

Intuitively for the current hardware:

- `raw` near `200` means brighter ambient light;
- `raw` near `3200` means a darker scene.

### Choosing a Good Range

If the range is chosen well:

- real light changes occupy a meaningful part of the `0.0..1.0` interval;
- the algorithm does not hit `0` or `1` too often;
- the brightness curve behaves predictably.

If the range is chosen poorly:

- too many values get stuck at the lower or upper boundary;
- normalized output loses sensitivity;
- auto-brightness becomes either too sluggish or too abrupt in a narrow range.

## 1.5. What Happens after Normalization

After normalization, `pc-app` sends the value through the brightness pipeline.

Parameters used in this stage:

- `adcMin`, `adcMax`, `invert` for input normalization;
- `emaAlpha` for exponential smoothing;
- `gamma` for optional gamma correction after smoothing;
- `minPercent`, `maxPercent` for the final allowed brightness range;
- `brightness.curve` for mapping `lightPercent -> brightnessPercent`;
- `hysteresisPercent` for the minimum brightness change worth applying;
- `maxBrightnessStepPercent` for the maximum change per cycle.

Computation order:

1. `raw` becomes `normalized` in the range `0.0..1.0`;
2. `normalized` is smoothed with `EMA`;
3. `gamma` is optionally applied to the smoothed value;
4. the result is converted to `requestedBrightness`;
5. `requestedBrightness` is clamped to `minPercent..maxPercent`;
6. if the change is too small, `hysteresis` blocks it;
7. if the change is too large, the step is limited by `maxBrightnessStepPercent`.

### `EMA` Formula

If this is not the first value:

```text
ema = (emaAlpha * normalized) + ((1.0 - emaAlpha) * previousEma)
```

If this is the first value:

```text
ema = normalized
```

History enters the pipeline here:

- in the first cycle, `ema` is just the current `normalized`;
- in each next cycle, the current `normalized` is mixed with the previous `ema`;
- `previousEma` is the smoothed value from the previous step, not the previous `raw`.

Written across several cycles:

```text
cycle 1:
ema1 = normalized1

cycle 2:
ema2 = (emaAlpha * normalized2) + ((1.0 - emaAlpha) * ema1)

cycle 3:
ema3 = (emaAlpha * normalized3) + ((1.0 - emaAlpha) * ema2)
```

So the current `ema` always contains some contribution from earlier measurements, with older samples contributing less over time.

A larger `emaAlpha` makes the system react faster.
A smaller `emaAlpha` makes it smoother but slower.

### Gamma Correction Formula

If `gamma` is set:

```text
effectiveValue = pow(ema, gamma)
```

If `gamma` is not set:

```text
effectiveValue = ema
```

In practice:

- `gamma > 1` changes sensitivity more strongly across the range;
- `gamma = 1` is effectively linear;
- without `gamma`, the smoothed value is used as-is.

### Converting to Brightness Percent

If `brightness.curve` is missing or has fewer than two points, linear mapping is used:

```text
requestedBrightness =
    minPercent + effectiveValue * (maxPercent - minPercent)
```

The result is then rounded to a whole percent.

If `brightness.curve` is present:

1. `effectiveValue` is converted to `lightPercent`:

```text
lightPercent = clamp(effectiveValue * 100.0, 0.0, 100.0)
```

2. two neighboring curve points are found:

```text
(left.lightPercent, left.brightnessPercent)
(right.lightPercent, right.brightnessPercent)
```

3. linear interpolation is performed between them:

```text
ratio = (lightPercent - left.lightPercent) / (right.lightPercent - left.lightPercent)
requestedBrightness =
    left.brightnessPercent +
    ratio * (right.brightnessPercent - left.brightnessPercent)
```

If `lightPercent` is left of the first point, the first point brightness is used.
If it is right of the last point, the last point brightness is used.

After that, the result is still clamped:

```text
requestedBrightness = clamp(requestedBrightness, minPercent, maxPercent)
```

### Hysteresis Formula

If there is already a previously applied brightness `lastAppliedBrightness`, the application compares it with the new request:

```text
abs(requestedBrightness - lastAppliedBrightness) < hysteresisPercent
```

Important:

- the comparison does not happen immediately after reading `raw`;
- it is not comparing against the previous `raw`;
- it is not comparing against the previous `normalized` or previous `EMA`;
- it happens after normalization, smoothing, gamma correction, curve interpolation, and range clamping;
- the actual comparison is between:
  - the new `requestedBrightness` from the current cycle;
  - the previous `lastAppliedBrightness` that was really applied before.

If the condition is true, the new brightness is not sent to the monitor.
This prevents small sensor fluctuations from causing unnecessary changes.

### Maximum Step Limit

If the change should still be applied, the application also limits how fast brightness can move:

```text
delta = requestedBrightness - lastAppliedBrightness
```

If:

```text
abs(delta) > maxBrightnessStepPercent
```

then only one step is taken:

```text
targetBrightness =
    lastAppliedBrightness + sign(delta) * maxBrightnessStepPercent
```

Otherwise:

```text
targetBrightness = requestedBrightness
```

`targetBrightness` is what gets sent further to `WMI` or `DDC/CI`.

### What This Means Practically

- `raw` is not a ready-made brightness percentage;
- even `normalized` is not the final brightness;
- the result depends on smoothing, gamma, the response curve, range limits, hysteresis, and step limiting.

That is why `raw` must not be treated as a direct brightness value. It is only the input to the brightness pipeline.

## 2. Sending Brightness to the Monitor through `DDC/CI`

## 2.1. What `DDC/CI` Means in This Project

For external monitors, the current Windows implementation uses `DDC/CI` through `dxva2.dll`.

At code level this means:

- the app enumerates displays through `EnumDisplayMonitors`;
- it gets physical monitors through `GetPhysicalMonitorsFromHMONITOR`;
- it tries to read brightness through `GetMonitorBrightness`;
- it tries to write brightness through `SetMonitorBrightness`.

So the working model is:

1. the sensor sends `raw`;
2. the application computes target brightness in the `0..100` range;
3. the application sends that target to the Windows monitor API;
4. Windows, the GPU driver, and the monitor stack deliver the command over `DDC/CI`.

## 2.2. What This Means Practically for the Current Project

In the current project, the data path is:

- `ESP32-C6` sends telemetry to `pc-app`;
- `pc-app` computes the target brightness;
- `pc-app` applies monitor brightness through `WMI` or `DDC/CI`.

There is no direct `I2C` bus from `ESP32-C6` to the monitor in the current implementation.

## 2.3. How to Check `DDC/CI` Brightness Support

Before relying on `DDC/CI`, check the monitor in this order:

1. the monitor should be an external display, not a built-in laptop panel;
2. the monitor OSD should ideally have a setting such as `DDC/CI = On`;
3. the monitor should be connected through an interface and cable that actually passes `DDC/CI`;
4. the Windows API should be able to discover the physical monitor;
5. at least one of these calls should succeed:
   - `GetMonitorBrightness(...)`
   - `SetMonitorBrightness(...)`

For this project, the practical support rule is:

- if the monitor appears through `DdcMonitor.Discover()`, that alone is not a full guarantee;
- if `GetMonitorBrightness(...)` or `SetMonitorBrightness(...)` works reliably, the monitor can be treated as usable for `DDC/CI` brightness control;
- if both fail, the monitor should be treated as unsupported for this method.

## 2.4. Current Implementation Behavior

The current implementation already does a reasonable support check:

- it first discovers monitors through `WMI` and `DDC/CI`;
- for `DDC/CI`, it tries to read the brightness range before writing;
- if reading the range fails, it still tries `SetMonitorBrightness(...)` with a `0..100` percentage;
- if writing fails, the monitor is treated as problematic.

This is useful because some monitors do not report brightness properly but still accept writes.

## 2.5. Practical Support States

For this project, a monitor can be treated as:

- `supported`:
  - it was discovered as a physical monitor;
  - at least one test brightness write succeeded.
- `partially_supported`:
  - brightness read does not work;
  - brightness write works.
- `unsupported`:
  - the monitor is not discovered as controllable;
  - or brightness write fails.

## 2.6. Recommended Application Order

The correct order is:

1. discover monitor-control candidates;
2. separate built-in displays (`WMI`) from external ones (`DDC/CI`);
3. verify practical read/write capability for each monitor;
4. only then enable automatic brightness updates;
5. if a specific monitor keeps failing, disable that monitor instead of breaking the whole sensor pipeline.

This is the most robust approach when some monitors are only partially compatible.

## Related Documents

- [protocol.md](./protocol.md) - current wire contract
- [firmware.md](./firmware.md) - current `ESP32-C6` firmware
- [build.md](./build.md) - running the Windows application

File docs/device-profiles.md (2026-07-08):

# Device Settings

`pc-app` now uses one built-in LumaBloom settings baseline instead of multiple hardware profiles.

## How It Works

1. The app probes available COM ports.
2. It accepts the first port that emits valid JSON telemetry matching the LumaBloom protocol:
   `{"id":"lumabloom","ts":1234567,"raw":1840}`
3. It resolves effective runtime settings as:
   `built-in defaults + appsettings.json overrides`
4. It applies brightness using the live `raw` sensor value and the active response curve.

There is no longer any runtime profile selection based on `deviceId + sensorId`.

## Built-In Defaults

The single built-in baseline matches the current ESP32-C6 + KY-018 setup:

- `measurementKind=Adc`
- `connection.baudRate=115200`
- `connection.discoveryTimeoutMs=2500`
- `processing.adcMin=200`
- `processing.adcMax=3200`
- `processing.invert=true`
- `processing.emaAlpha=0.2`
- `processing.hysteresisPercent=1`
- `processing.maxBrightnessStepPercent=2`
- `processing.gamma=1.0`
- `brightness.minPercent=10`
- `brightness.maxPercent=100`
- default curve points at `0/25/50/75/100`

## User Config

You can keep `appsettings.json` minimal:

```json
{
  "brightness": {
    "minPercent": 10,
    "maxPercent": 100
  }
}
```

For a full example with every common override populated, see [appsettings.esp32c6.example.json](../pc-app/appsettings.esp32c6.example.json).

## Config Parameters

Top-level sections:

- `connection` - optional serial transport overrides
- `processing` - optional raw-signal processing overrides
- `brightness` - optional output brightness bounds and response curve
- `ui` - runtime UI preferences

### `connection`

- `connection.baudRate` (`number`, optional): must be greater than `0`
- `connection.discoveryTimeoutMs` (`number`, optional): must be greater than `0`

### `processing`

- `processing.adcMin` (`number`, optional): must be less than `processing.adcMax`
- `processing.adcMax` (`number`, optional): must be greater than `processing.adcMin`
- `processing.invert` (`bool`, optional): use `true` when more ambient light produces a lower raw ADC value
- `processing.emaAlpha` (`number`, optional): valid range `(0, 1]`
- `processing.hysteresisPercent` (`number`, optional): valid range `0..100`
- `processing.maxBrightnessStepPercent` (`number`, optional): valid range `1..100`
- `processing.gamma` (`number`, optional): must be `> 0`

### `brightness`

- `brightness.minPercent` (`number`, optional): valid range `0..100`
- `brightness.maxPercent` (`number`, optional): valid range `0..100`, and must be `>= minPercent`
- `brightness.curve` (`array`, optional): sorted or unsorted list of `{ "lightPercent": 0..100, "brightnessPercent": 0..100 }`

Curve validation:

- at least 2 points are required if `brightness.curve` is present
- `lightPercent` values must be unique
- extra anchor points are valid and may be written by the UI in addition to the base `0/25/50/75/100` points

### `ui`

- `ui.language` (`string`): one of `auto`, `en`, `ru`, `es`

## Brightness Curve Editing

The response curve is stored in `brightness.curve` as a sorted list of `{ lightPercent, brightnessPercent }` points.

Important behavior:

- The settings screen still presents the familiar five visible curve positions at `0/25/50/75/100`.
- The `Current light` action in the UI is additive: it uses the latest live ambient reading as an anchor and rebuilds the stored curve around that point.
- The current ambient percent for this action is derived from the live `raw` sensor field together with the active `processing.adcMin`, `processing.adcMax`, and `processing.invert` values.
- When needed, the saved curve may contain extra points beyond the base five, for example `{ "lightPercent": 16, "brightnessPercent": 60 }`.
- Extra anchor points are valid configuration and are used by interpolation so that the chosen current-light target is preserved exactly.

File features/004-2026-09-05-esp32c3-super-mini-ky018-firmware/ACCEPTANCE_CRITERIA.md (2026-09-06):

# Критерии приёмки: прошивка ESP32-C3 Super Mini + KY-018 без дисплея

## Структура и сборка

1. **AC-1 (FR-1, FR-9):** `firmware/firmware_esp32c3_supermini/` является самостоятельным ESP-IDF-проектом, а `idf.py set-target esp32c3` и последующий clean build завершаются успешно.
2. **AC-2 (FR-1):** список исходников и зависимостей C3-проекта не содержит LCD/UI/animation/button модулей и не ссылается на исходники `firmware_esp32c6`.
3. **AC-3 (FR-9):** `sdkconfig.defaults` задаёт target `esp32c3`, USB Serial/JTAG console и отключённую default UART console; generated `sdkconfig` не добавлен в git.

## Подключение и ADC

4. **AC-4 (FR-2, FR-3):** code review подтверждает `GPIO4 -> ADC1_CH4`, `ADC_UNIT_1`, `12 bit` и `12 dB`; hardware smoke test использует `KY-018 VCC -> 3V3`, `GND -> GND`, `AO/S -> GPIO4`.
5. **AC-5 (FR-3):** опубликованный `raw` равен результату `adc_oneshot_read()` данного цикла и не проходит через проценты, gamma, EMA, offset или усреднение.
6. **AC-6 (FR-2, FR-6):** прошивка не конфигурирует `GPIO18` и `GPIO19` как прикладные GPIO; после flash/reset USB COM-порт остаётся доступным в Windows.

## Телеметрия

7. **AC-7 (FR-4, FR-5):** после запуска устройство отправляет строки, разбираемые как JSON с точным `id="lumabloom"`, целочисленными `ts` и `raw`, и завершающим `\n`.
8. **AC-8 (FR-5):** в telemetry-объекте нет обязательных дополнительных полей, а `raw` помещается в signed 32-bit integer.
9. **AC-9 (FR-4):** в 30-секундном serial capture после первой секунды медианный интервал между валидными telemetry-строками находится в диапазоне `150..300 ms`; кратковременные отклонения планировщика не считаются ошибкой.
10. **AC-10 (FR-4):** `ts` не уменьшается между последовательными сообщениями в одном запуске и после reset может начинаться заново.
11. **AC-11 (FR-3):** при последовательном освещении и затемнении KY-018 выборка `raw` показывает воспроизводимое изменение в одном направлении, достаточное для настройки `adcMin`, `adcMax` и `invert`; точные абсолютные границы не фиксируются критерием.

## Ошибки и восстановление

12. **AC-12 (FR-7):** unit/code-path проверка подтверждает, что ошибка `adc_oneshot_new_unit`, конфигурации канала или `adc_oneshot_read` логируется и не формирует telemetry-строку.
13. **AC-13 (FR-7):** после имитированной либо аппаратно воспроизведённой ошибки следующий цикл пытается повторно инициализировать sensor path, а после восстановления валидная телеметрия возобновляется без reset.
14. **AC-14 (FR-7):** при отсутствии открытого serial consumer устройство продолжает sensor cycle и после повторного открытия COM-порта снова выдаёт актуальные показания.

## Совместимость с Windows-приложением

15. **AC-15 (FR-5, FR-8):** существующие тесты `SensorMessageParserTests` и `SerialPortDiscoveryTests` проходят без изменения ожидаемого протокола.
16. **AC-16 (FR-8):** установленный `pc-app` находит C3-плату как LumaBloom через штатный auto-discovery на `115200` без изменений исходного кода приложения.
17. **AC-17 (FR-8):** с фактически настроенными `adcMin`, `adcMax` и `invert` изменение света меняет рассчитанный light percent и целевую яркость монитора; настройка сохраняется существующим механизмом приложения.
18. **AC-18 (FR-8):** прошивка не требует команды `calibrate` и не отправляет `calibrationResult` для начала обычной работы.

## Release и прошивка

19. **AC-19 (FR-10):** `python build_merged.py --dry-run --tag 1.2.3` завершается успешно, перечисляет build/merge-команды для единственного варианта и не создаёт артефакты.
20. **AC-20 (FR-10):** `python build_merged.py --tag 1.2.3` создаёт `luma_bloom_esp32c3-supermini_1.2.3_merged.bin` и одноимённый `.manifest.json` в `build/release/`.
21. **AC-21 (FR-10):** manifest имеет schema v1 и точные значения `version="1.2.3"`, `variant="esp32c3-supermini"`, `board="esp32-c3-super-mini"`, `flashMethod="esptool"`, `chip="esp32c3"`, `baudRate=460800`, `offset="0x0"`, а `fileName` совпадает с бинарником.
22. **AC-22 (FR-10):** повторный запуск для того же tag очищает только C3-артефакты этого tag и не удаляет ESP32-C6 release-файлы; `--skip-build` пересобирает merged image из валидных существующих build outputs либо завершается с ненулевым кодом при их отсутствии.
23. **AC-23 (FR-10):** merged binary успешно прошивается по `0x0` через `esptool --chip esp32c3`, после reset запускается и удовлетворяет AC-7—AC-11.
24. **AC-24 (FR-10):** `BundledFirmwareLocator` принимает C3 manifest, а `FirmwareFlashService` формирует команду с `--chip esp32c3`, manifest baud rate и offset без специальной ветки в `pc-app`.

## Документация и регрессия

25. **AC-25 (FR-11):** README и hardware/firmware docs содержат C3 wiring, build/flash/release-команды, USB Serial/JTAG ограничение и порядок настройки ADC-диапазона.
26. **AC-26 (FR-11):** документация явно отделяет общую для C6/C3 верхнюю часть цветка от C6-специфичного нижнего горшка и сообщает, что отдельный горшок и крепление платы для Super Mini пока отсутствуют.
27. **AC-27 (совместимость):** ESP32-C6 default и touch builds либо их `build_merged.py --dry-run` проверки продолжают работать, а существующие telemetry/parser tests проходят.
28. **AC-28 (нефункциональные требования):** code review runtime loop подтверждает отсутствие heap allocation, создания task/handle и накопления очереди на каждой итерации; все долгоживущие ресурсы создаются при инициализации или повторной инициализации после ошибки.
29. **AC-29 (нефункциональные требования):** protocol id и read interval имеют по одному владельцу в `app_config.h`, а publisher получает их через интерфейс либо include без дублирования literal в runtime-модулях.

## Минимальный протокол ручной проверки

1. Собрать C3-проект из чистого build-каталога.
2. Подключить KY-018 по документированной схеме и прошить merged binary.
3. Записать 30 секунд serial output на `115200`, проверить JSON, интервал и монотонность `ts`.
4. Поочерёдно закрыть датчик и осветить его, зафиксировать полезный диапазон и направление `raw`.
5. Запустить `pc-app`, убедиться в auto-discovery и изменении вычисляемой яркости после настройки диапазона.
6. Вызвать ошибку ADC управляемым test fault injection, убрать fault и проверить автоматическую повторную инициализацию и возобновление.

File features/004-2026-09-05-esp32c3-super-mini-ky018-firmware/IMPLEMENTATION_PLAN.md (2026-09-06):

# План реализации: прошивка ESP32-C3 Super Mini + KY-018 без дисплея

## Статус и границы

Программная часть реализована 2026-09-06 в новом треке `firmware/firmware_esp32c3_supermini/` и связанной документации. Wire-протокол и production-код `pc-app` не изменены; тесты приложения используются как regression/contract validation. Аппаратная приёмка остаётся ожидающей физической платы и KY-018.

## Архитектурное решение

Создать независимый ESP-IDF-проект вместо расширения `firmware_esp32c6` compile-time флагами. C3-прошивка имеет один sensor task и четыре небольших модуля: конфигурация, модель reading, ADC-драйвер KY-018 и JSONL publisher. Display, shared mutable UI state, calibration command reader и mutex не нужны.

Поток данных:

```text
KY-018 AO -> GPIO4 / ADC1_CH4 -> adc_oneshot_read()
          -> device_reading_t { ts_ms, raw_adc, valid }
          -> telemetry_serial_publish()
          -> USB Serial/JTAG -> COM port -> pc-app parser/discovery
```

## Этап 1. Каркас ESP-IDF-проекта

Создать `firmware/firmware_esp32c3_supermini/`:

- `CMakeLists.txt` с `project(brightness_sensor_esp32c3_supermini)`;
- `sdkconfig.defaults` с `CONFIG_IDF_TARGET="esp32c3"`, частотой CPU по умолчанию для проекта, `CONFIG_ESP_CONSOLE_USB_SERIAL_JTAG=y`, `CONFIG_ESP_CONSOLE_UART_DEFAULT=n` и info logging;
- `main/CMakeLists.txt`, регистрирующий только `app_main.c`, `sensor_ky018.c`, `telemetry_serial.c` и зависимости `esp_adc`, `esp_timer`/соответствующий timer component;
- `main/app_config.h` с `APP_PROTOCOL_ID`, `APP_READ_INTERVAL_MS`, ADC unit/channel/GPIO, bit width и attenuation;
- `main/device_reading.h` с `uint64_t ts_ms`, `int raw_adc`, `bool valid`.

Не добавлять `sdkconfig`, build outputs, managed components и зависимости ESP32-C6. Проверить target clean build. Покрывает AC-1—AC-3, AC-29.

## Этап 2. Драйвер KY-018

Реализовать `main/sensor_ky018.h/.c` по текущему ADC oneshot pattern, но без полей нормализации:

1. `sensor_ky018_init()` валидирует указатель, идемпотентно возвращает успех для готового handle, создаёт `ADC_UNIT_1`, конфигурирует `ADC_CHANNEL_4` как `ADC_BITWIDTH_12` + `ADC_ATTEN_DB_12` и логирует GPIO/channel.
2. При частично завершившейся инициализации освобождает созданный ADC unit до возврата ошибки.
3. `sensor_ky018_read()` валидирует состояние, читает один raw result, записывает его в `device_reading_t` и только после успешного чтения ставит `valid=true`.
4. Добавить явный `sensor_ky018_deinit()` либо `sensor_ky018_reset()` для удаления существующего unit handle после read error. Sensor task вызывает его перед следующей повторной инициализацией, чтобы не оставлять stale handle и не исчерпывать ADC resources.

Конфигурация `GPIO4/ADC1_CH4` подтверждается таблицей pin functions ESP32-C3; `GPIO18/19` не затрагиваются. Покрывает AC-4—AC-6, AC-12—AC-13.

## Этап 3. JSONL publisher и runtime loop

Реализовать `main/telemetry_serial.h/.c`:

- принимать protocol id и валидный reading;
- печатать только `{"id":"%s","ts":<uint64>,"raw":<int>}\n` через `printf`;
- вызывать `fflush(stdout)` после строки;
- ничего не публиковать для null/invalid input.

Реализовать `main/app_main.c`:

1. Логировать board target, protocol id и interval.
2. Создать статический `sensor_ky018_t`; отдельная установка USB driver не нужна, потому что stdout направлен в USB Serial/JTAG через `sdkconfig.defaults`.
3. Запустить один `sensor_task` с достаточным фиксированным stack и обычным приоритетом.
4. На каждой итерации сформировать invalid reading, выполнить идемпотентную инициализацию, затем чтение.
5. Только при успешном чтении установить `ts_ms = esp_timer_get_time()/1000` и вызвать publisher.
6. При любой sensor error залогировать `esp_err_to_name`, deinit/reset sensor state и перейти к `vTaskDelay(pdMS_TO_TICKS(200))`.
7. Не создавать serial command task, calibration state, mutex, display task или sleep policy.

Если `printf` не предоставляет возвращаемое значение полного размера, записать warning без остановки sensor loop; повторная публикация происходит на следующем цикле, очередь и повтор старого reading не вводятся. Это сохраняет latest-data semantics и не создаёт backpressure. Покрывает AC-7—AC-14, AC-18, AC-28—AC-29.

## Этап 4. Release adapter

Создать `firmware/firmware_esp32c3_supermini/build_merged.py`, используя контракт и CLI текущего C6 adapter, но с одним immutable variant:

- variant id `esp32c3-supermini`;
- board id `esp32-c3-super-mini`;
- ESP-IDF target/esptool chip `esp32c3`;
- build tree `build/variants/esp32c3-supermini`;
- output `build/release/luma_bloom_esp32c3-supermini_<tag>_merged.bin`;
- manifest значения из FR-10.

Сохранить параметры `--tag`, `--variant`, `--skip-build`, `--idf-py`, `--idf-python`, `--dry-run`, `--list`. Без `--variant` строится единственный поддерживаемый вариант. Build-команда передаёт `-D PROJECT_VER=<tag>`, merge использует сгенерированный ESP-IDF `flash_args`, а очистка ограничивается C3 release directory и выбранным tag. Ошибки build/merge/manifest завершают скрипт ненулевым кодом.

Проверки:

- `python build_merged.py --list`;
- `python build_merged.py --dry-run --tag 1.2.3`;
- полный build и manifest inspection;
- `--skip-build` после полного build и негативный запуск без outputs;
- flash merged image по `0x0` и boot smoke test.

Покрывает AC-19—AC-24.

## Этап 5. Документация

Обновить только пользовательские документы, затронутые новым поддерживаемым треком:

- `README.md`: два firmware target, C3 без дисплея, обновлённая карта и How It Works без утверждения, что LCD обязателен;
- `firmware/README.md`: добавить C3 reference project;
- новый `firmware/firmware_esp32c3_supermini/README.md`: назначение, pinout, USB Serial/JTAG, build, flash, merged release, telemetry, troubleshooting;
- `docs/getting-started.md`: отдельные ветки C6 и C3 setup, ожидаемый результат без LCD для C3;
- `docs/firmware.md`: индекс двух проектов и точные команды target/chip;
- `docs/protocol.md`: перечислить C6 и C3 как producers общего raw-контракта;
- `docs/device-profiles.md`: пояснить отсутствие отдельного C3 runtime profile и необходимость подстройки raw range;
- `hardware/README.md`, `hardware/WIRING.md`, `hardware/BOM.md`, `hardware/ASSEMBLY.md`: новый hardware track, общая верхняя часть цветка и явное отсутствие отдельного C3-горшка и крепления платы;
- `CONTRIBUTING.md`: firmware validation для обоих проектов;
- `docs/skills-for-users.md`: третий release variant и пример точного C3 artifact name.

Не создавать отдельный `appsettings.esp32c3` с непроверенными ADC-границами. В документации использовать baseline `200..3200`, `invert=true` только как стартовую точку и описать измерение фактических bright/dark значений. Покрывает AC-25—AC-27.

## Этап 6. Проверка совместимости

### Автоматическая

1. C3: `idf.py set-target esp32c3`, clean `idf.py build`.
2. C3 release: dry-run, full `build_merged.py --tag <test-tag>`, manifest validation и `--skip-build`.
3. C6 regression: `python build_merged.py --dry-run --tag <test-tag>`; при доступном toolchain — builds обоих C6 variants.
4. PC contracts из `pc-app/`: `dotnet test brightness-sensor.sln`, в особенности `BrightnessSensor.DeviceReading.Tests` и `BundledFirmwareLocatorTests`/`FirmwareFlashService` tests.
5. Если текущие locator tests не покрывают `chip="esp32c3"`, добавить только тестовый fixture/кейс, не меняя production code: manifest принимается, а process arguments содержат `--chip esp32c3`.

### Аппаратная

Выполнить минимальный протокол из `ACCEPTANCE_CRITERIA.md`: flash, 30-секундный capture, bright/dark response, restart, sensor fault/recovery, auto-discovery в `pc-app` и flash merged image из Update либо эквивалентной команды `esptool`.

Если hardware validation недоступна исполнителю, feature нельзя считать полностью принятой: build и contract результаты фиксируются отдельно, а AC-6, AC-9, AC-11, AC-13—AC-14, AC-16—AC-17 и AC-23 остаются ожидающими проверки на устройстве.

## Соответствие требований владельцам реализации

| Область | Требования | Критерии | Владелец |
| --- | --- | --- | --- |
| ESP-IDF project | FR-1, FR-9 | AC-1—AC-3, AC-29 | CMake + `sdkconfig.defaults` |
| Hardware/ADC | FR-2, FR-3 | AC-4—AC-6, AC-11 | `app_config`, `sensor_ky018` |
| Runtime/telemetry | FR-4—FR-7, NFR | AC-7—AC-14, AC-28—AC-29 | `app_main`, `telemetry_serial` |
| PC compatibility | FR-8 | AC-15—AC-18 | существующие contracts/tests |
| Release | FR-10 | AC-19—AC-24 | `build_merged.py`, manifest |
| Documentation | FR-11 | AC-25—AC-27 | root/docs/hardware READMEs |

## Отклонённые варианты

- **Добавить C3 как `#ifdef` в проект C6.** Отклонено: board не использует LCD, а общая сборка связала бы независимые target, sdkconfig, dependencies и release variants.
- **Передавать процент вместо raw ADC.** Отклонено: нарушает действующий wire-контракт и переносит пользовательскую калибровку из `pc-app` в firmware.
- **Добавить новый protocol id или device profile.** Отклонено: текущая совместимость определяется `id="lumabloom"` и наличием `raw`; различение платы не нужно для runtime.
- **Использовать GPIO5/ADC2.** Отклонено: ESP-IDF документирует ограничения ADC2 oneshot на ESP32-C3; `GPIO4/ADC1_CH4` доступен и согласуется с существующей схемой KY-018.
- **Копировать calibration/serial-command код C6.** Отклонено: текущий `pc-app` не требует firmware calibration, а для устройства без UI это добавляет неиспользуемое состояние и двусторонний протокол.

## Риски и меры

- Разные клоны Super Mini могут разводить USB иначе. Поддерживаемая ревизия ограничена платами со встроенным USB Serial/JTAG на USB-разъёме; это проверяется до flash.
- Разброс KY-018 и ADC C3 может сделать baseline неточным. Протокол сохраняет raw, а документация требует hardware tuning через существующие app settings.
- Отключение USB consumer может влиять на buffering. Runtime не входит в sleep и не ждёт входных команд; проверяется закрытием и повторным открытием COM-порта.
- Добавление третьего firmware artifact может выявить неоднозначность выбора в Update UI. Текущий UI уже читает список manifests; функциональные изменения выбора не входят в scope, но AC-24 проверяет корректную передачу `chip` выбранного C3 manifest.

## Готовность

Материальных открытых вопросов нет. Этапы 1—5 и автоматическая часть этапа 6 выполнены; завершение полной приёмки требует аппаратной проверки на ESP32-C3 Super Mini с KY-018.

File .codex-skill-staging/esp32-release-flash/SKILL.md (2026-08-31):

---
name: esp32-release-flash
description: Build merged release binaries for every firmware project and hardware variant in the LumaBloom repository, and optionally flash one explicitly selected ESP32 artifact. Use for firmware release builds, merged .bin generation, or USB flashing.
---

# Esp32 Release Flash

## Overview

Build every release-ready firmware artifact through the scripts owned by the firmware projects. When requested, flash one explicitly selected merged binary.

## Workflow

1. Resolve the artifact version from the same MinVer configuration as `pc-app`. Pass `--tag` only when the user explicitly requests a version override.
2. Run `scripts/build_release_and_flash.py` from the repository root. It discovers every firmware project and invokes its required `build_merged.py` with the resolved version.
3. Before each project build, remove old binaries and manifests matching the resolved version. Treat a firmware directory without `build_merged.py`, or an artifact without its manifest, as an error.
4. If the user asks to flash and multiple artifacts exist, require the exact `--firmware-file`. Never choose a hardware variant implicitly.
5. Use `--skip-build` only when the user explicitly wants to reuse valid existing variant build artifacts.
6. Report:
   - the generated binary path
   - the exact filename
   - whether flashing was performed
   - any follow-up action the user should take on the device

## Commands

### Build a readable merged binary

```powershell
python .codex-skill-staging/esp32-release-flash/scripts/build_release_and_flash.py --repo-root .
```

### Create a readable binary from existing build artifacts

```powershell
python .codex-skill-staging/esp32-release-flash/scripts/build_release_and_flash.py --repo-root . --skip-build
```

### Build and flash in one step

```powershell
python .codex-skill-staging/esp32-release-flash/scripts/build_release_and_flash.py --repo-root . --tag 2.1.0 --flash-port COM8 --firmware-file luma_bloom_esp32c6-display_2.1.0_merged.bin
```

## Naming Rules

- Each firmware project owns its artifact names.
- Unless overridden, the tag is `pc-app`'s MinVer version with build metadata after `+` removed, matching `AppVersion.Current`.
- Every artifact must include the requested tag and end in `_merged.bin`.
- Every artifact must have a `<binary>.manifest.json` sidecar.
- Each project writes artifacts to its own `build/release/` directory.

See `references/output-conventions.md` for the exact naming and output rules.

## Notes

- Firmware-specific build commands belong in each project's `build_merged.py`, not in this skill. The project script may use ESP-IDF, Arduino, PlatformIO, STM32 tooling, or any other required toolchain.
- The current ESP32-C6 project builds both `esp32c6-display` and `esp32c6-touch` by default.
- When flashing, it uses `esptool` against the merged binary at `0x0`.

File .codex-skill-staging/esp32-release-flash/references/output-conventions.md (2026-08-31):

# Output Conventions

- Required project entrypoint: `firmware/<project>/build_merged.py`
- Output directory per project: `firmware/<project>/build/release/`
- Required filename suffix: `_<tag>_merged.bin`
- Required manifest: `<binary>.manifest.json` using schema version `1`
- Remove old binaries and manifests for the requested tag before building
- Default `<tag>` source: the MinVer version of `pc-app/BrightnessSensor.ConsoleApp`, normalized exactly like `AppVersion.Current`
- Current ESP32-C6 outputs:
  - `luma_bloom_esp32c6-display_<tag>_merged.bin`
  - `luma_bloom_esp32c6-touch_<tag>_merged.bin`
- Use the merged binary for releases and for full-device flashing at `0x0`
- Report every absolute output path back to the user

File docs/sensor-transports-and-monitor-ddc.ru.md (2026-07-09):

# Чтение сенсора по USB и управление яркостью монитора

- [English](sensor-transports-and-monitor-ddc.md)
- [Русский](sensor-transports-and-monitor-ddc.ru.md)

Этот документ объясняет две практические части системы в её текущем состоянии:

1. как считывать и интерпретировать показания сенсора по `USB`;
2. как передавать рассчитанную яркость в монитор через `DDC/CI` и как заранее понять, поддерживает ли монитор такое управление.

## Коротко о текущем состоянии репозитория

Сейчас в этом репозитории реально реализовано:

- получение телеметрии от устройства по `USB Serial`;
- чтение newline-delimited `JSON` сообщений вида `{"id":"lumabloom","ts":1234567,"raw":1840}`;
- интерпретация поля `raw` как единственного рабочего значения сенсора;
- управление яркостью мониторов в `Windows` через:
  - `WMI` для встроенных дисплеев;
  - `DDC/CI` для внешних мониторов.

Сейчас не реализовано:

- прямое управление монитором из прошивки `ESP32-C6` по физической шине `I2C`.

Важно: в контексте ПК-приложения `DDC/CI` обычно проходит по служебным линиям интерфейса монитора и вызывается через API Windows. Это не то же самое, что напрямую управлять monitor `I2C` из `ESP32`.

## 1. Как читать и интерпретировать значения сенсора

## 1.1. Источник истины

Для текущего `ESP32-C6` источником истины является поле `raw` в телеметрии:

```json
{"id":"lumabloom","ts":1234567,"raw":1840}
```

Где:

- `id` должен быть равен `lumabloom`;
- `ts` - время с момента старта устройства в миллисекундах;
- `raw` - сырое значение `ADC`.

Поле `raw` сейчас является единственным обязательным измерением, из которого приложение считает яркость.

## 1.2. Как устроен transport в текущем проекте

### `USB`

В текущем проекте `USB` - это основной transport между устройством и `pc-app`.

Практически это означает:

- устройство появляется в Windows как `COM`-порт;
- `pc-app` сканирует доступные `COM`-порты;
- первым подходящим считается порт, который выдаёт валидные JSONL-сообщения с `id="lumabloom"` и полем `raw`.

Параметры текущего wire contract:

- скорость: `115200 baud`;
- разделитель сообщений: `\n`;
- формат: одна JSON-структура на строку;
- типичный интервал публикации: около `500 ms`.

Текущий `USB Serial` wire contract устроен как последовательный строковый поток:

- есть байтовый последовательный канал;
- есть строковый фрейминг по `\n`;
- каждая завершённая строка должна быть самостоятельным JSON-сообщением.

## 1.3. Как валидировать входящее сообщение

Сообщение можно считать пригодным к обработке, если одновременно выполняются условия:

- строка успешно дочитана до `\n`;
- строка является валидным `JSON`;
- корневой элемент - объект;
- есть строковое поле `id`;
- `id == "lumabloom"`;
- есть числовое поле `ts`;
- есть числовое поле `raw`.

Если хотя бы одно из этих условий не выполнено, сообщение не должно участвовать в расчёте яркости.

## 1.4. Как интерпретировать `raw`

В текущей реализации для обработки `raw` используются такие рабочие значения:

- `adcMin = 200`
- `adcMax = 3200`
- `invert = true`

В пользовательской конфигурации эти же параметры задаются как:

- `processing.adcMin`
- `processing.adcMax`
- `processing.invert`

Текущие встроенные значения по умолчанию в `pc-app`:

- `processing.adcMin = 200`
- `processing.adcMax = 3200`
- `processing.invert = true`

Это означает:

- `200` - это нижняя граница рабочего диапазона и в текущей схеме соответствует самой светлой сцене;
- `3200` - это верхняя граница рабочего диапазона и в текущей схеме соответствует самой тёмной сцене;
- если `raw` уходит ниже `200`, приложение всё равно считает его равным `200`;
- если `raw` уходит выше `3200`, приложение всё равно считает его равным `3200`;
- после нормализации значение инвертируется, потому что на текущей схеме больше света даёт меньшее `raw`.

### Как влияют параметры

#### `processing.adcMin`

Это нижняя граница рабочего диапазона.

Если `raw < adcMin`, приложение считает значение равным `adcMin`.

Практический смысл:

- меньшее `adcMin` расширяет рабочий диапазон вниз;
- большее `adcMin` раньше начинает считать сцену "достаточно яркой";
- слишком большое `adcMin` может сжать полезную часть диапазона и сделать систему менее чувствительной к яркому свету.

#### `processing.adcMax`

Это верхняя граница рабочего диапазона.

Если `raw > adcMax`, приложение считает значение равным `adcMax`.

Практический смысл:

- большее `adcMax` расширяет рабочий диапазон вверх;
- меньшее `adcMax` раньше начинает считать сцену "достаточно тёмной";
- слишком маленькое `adcMax` может привести к тому, что разные тёмные сцены будут выглядеть для алгоритма почти одинаково.

#### `processing.invert`

Этот флаг определяет, в какую сторону читать рост `raw`.

Если:

```text
invert = false
```

то большее `raw` означает больше света после нормализации.

Если:

```text
invert = true
```

то после нормализации выполняется:

```text
normalized = 1.0 - normalized
```

и большее внешнее освещение соответствует меньшему `raw`.

Для текущего `KY-018` на этой схеме используется именно:

```text
invert = true
```

### Формула преобразования

Сначала входное значение ограничивается рабочим диапазоном:

```text
clamped = clamp(raw, adcMin, adcMax)
```

Затем нормализуется:

```text
normalized = (clamped - adcMin) / (adcMax - adcMin)
```

Если `invert = true`, выполняется ещё один шаг:

```text
normalized = 1.0 - normalized
```

Интуитивно для текущего железа:

- `raw` около `200` означает более яркое внешнее освещение;
- `raw` около `3200` означает более тёмную сцену.

### Что важно при настройке диапазона

Если диапазон выбран удачно:

- реальные изменения света занимают заметную часть интервала `0.0..1.0`;
- алгоритм не "упирается" слишком часто в `0` или `1`;
- кривая яркости работает предсказуемо.

Если диапазон выбран плохо:

- слишком много значений будет постоянно прижато к нижней или верхней границе;
- нормализованное значение потеряет чувствительность;
- автоподстройка яркости станет либо вялой, либо слишком резкой в узком диапазоне.

## 1.5. Что делать с нормализованным значением дальше

После нормализации текущая `pc-app` прогоняет значение через brightness pipeline.

Используемые параметры:

- `adcMin`, `adcMax`, `invert` - параметры нормализации входного `raw`;
- `emaAlpha` - коэффициент экспоненциального сглаживания;
- `gamma` - необязательная gamma-коррекция после сглаживания;
- `minPercent`, `maxPercent` - допустимый диапазон итоговой яркости;
- `brightness.curve` - кривая преобразования `lightPercent -> brightnessPercent`;
- `hysteresisPercent` - минимальное изменение яркости, при котором нужно что-то применять;
- `maxBrightnessStepPercent` - максимальный шаг яркости за один цикл.

Порядок вычислений:

1. из `raw` получается `normalized` в диапазоне `0.0..1.0`;
2. `normalized` сглаживается через `EMA`;
3. к сглаженному значению при необходимости применяется `gamma`;
4. результат переводится в `requestedBrightness`;
5. `requestedBrightness` зажимается в диапазон `minPercent..maxPercent`;
6. если изменение слишком маленькое, срабатывает `hysteresis` и новая яркость не применяется;
7. если изменение слишком большое, шаг ограничивается через `maxBrightnessStepPercent`.

### Формула `EMA`

Если это не первое значение, то:

```text
ema = (emaAlpha * normalized) + ((1.0 - emaAlpha) * previousEma)
```

Если это первое значение, то:

```text
ema = normalized
```

Зависимость от прошлых значений появляется именно здесь:

- в первом цикле `ema` просто становится равным текущему `normalized`;
- в каждом следующем цикле текущее `normalized` смешивается с предыдущим `ema`;
- то есть `previousEma` - это сглаженное значение, полученное на прошлом шаге, а не прошлый `raw`.

Если расписать два соседних цикла, получается так:

```text
cycle 1:
ema1 = normalized1

cycle 2:
ema2 = (emaAlpha * normalized2) + ((1.0 - emaAlpha) * ema1)

cycle 3:
ema3 = (emaAlpha * normalized3) + ((1.0 - emaAlpha) * ema2)
```

Поэтому текущее `ema` всегда содержит в себе след от предыдущих измерений, просто чем старее измерение, тем меньше его вклад.

Чем больше `emaAlpha`, тем быстрее система реагирует на изменения света.
Чем меньше `emaAlpha`, тем плавнее, но медленнее реакция.

### Формула gamma-коррекции

Если `gamma` задана:

```text
effectiveValue = pow(ema, gamma)
```

Если `gamma` не задана:

```text
effectiveValue = ema
```

На практике:

- `gamma > 1` сильнее меняет чувствительность в разных участках диапазона;
- `gamma = 1` фактически даёт линейное поведение;
- без `gamma` используется сглаженное значение как есть.

### Преобразование в процент яркости

Если кривая `brightness.curve` не задана или в ней меньше двух точек, используется линейная интерполяция:

```text
requestedBrightness =
    minPercent + effectiveValue * (maxPercent - minPercent)
```

Затем результат округляется до целого процента.

Если `brightness.curve` задана, то:

1. `effectiveValue` переводится в `lightPercent`:

```text
lightPercent = clamp(effectiveValue * 100.0, 0.0, 100.0)
```

2. затем ищутся две соседние точки кривой:

```text
(left.lightPercent, left.brightnessPercent)
(right.lightPercent, right.brightnessPercent)
```

3. и между ними делается линейная интерполяция:

```text
ratio = (lightPercent - left.lightPercent) / (right.lightPercent - left.lightPercent)
requestedBrightness =
    left.brightnessPercent +
    ratio * (right.brightnessPercent - left.brightnessPercent)
```

Если `lightPercent` левее первой точки, берётся яркость первой точки.
Если правее последней, берётся яркость последней точки.

После этого итог всё равно ограничивается:

```text
requestedBrightness = clamp(requestedBrightness, minPercent, maxPercent)
```

### Формула hysteresis

Если уже есть ранее применённая яркость `lastAppliedBrightness`, то приложение сравнивает её с новым запросом:

```text
abs(requestedBrightness - lastAppliedBrightness) < hysteresisPercent
```

Здесь важно:

- сравнение идёт не сразу после чтения `raw`;
- сравнение идёт не с предыдущим `raw`;
- сравнение идёт не с предыдущим `normalized` или `EMA`;
- сравнение выполняется после нормализации, сглаживания, gamma-коррекции, интерполяции по кривой и ограничения диапазона;
- то есть сравниваются именно:
  - новый `requestedBrightness`, посчитанный в текущем цикле;
  - предыдущий `lastAppliedBrightness`, который был реально применён к монитору раньше.

Если условие выполняется, новая яркость не отправляется в монитор.
То есть мелкие колебания сенсора не вызывают лишних переключений.

### Ограничение максимального шага

Если изменение всё-таки нужно применить, приложение дополнительно ограничивает скорость изменения:

```text
delta = requestedBrightness - lastAppliedBrightness
```

Если:

```text
abs(delta) > maxBrightnessStepPercent
```

то вместо полного перехода берётся только один шаг:

```text
targetBrightness =
    lastAppliedBrightness + sign(delta) * maxBrightnessStepPercent
```

Иначе:

```text
targetBrightness = requestedBrightness
```

Именно `targetBrightness` уходит дальше на применение через `WMI` или `DDC/CI`.

### Что это значит practically

- `raw` не является готовым процентом яркости;
- даже `normalized` ещё не является итоговой яркостью;
- итог зависит от сглаживания, gamma, кривой отклика, ограничений диапазона, hysteresis и ограничения шага.

Именно поэтому нельзя трактовать `raw` как готовый процент яркости. Это только вход brightness pipeline.

## 2. Как отправлять яркость в монитор через `DDC/CI`

## 2.1. Что такое `DDC/CI` в этом проекте

Для внешних мониторов текущая Windows-реализация использует `DDC/CI` через `dxva2.dll`.

На уровне кода это выглядит так:

- приложение перечисляет дисплеи через `EnumDisplayMonitors`;
- получает physical monitors через `GetPhysicalMonitorsFromHMONITOR`;
- пытается читать яркость через `GetMonitorBrightness`;
- пытается выставлять яркость через `SetMonitorBrightness`.

То есть рабочая модель такая:

1. сенсор прислал `raw`;
2. приложение посчитало target brightness в диапазоне `0..100`;
3. приложение отправило этот target в Windows monitor API;
4. Windows / драйвер / мониторный стек уже доставляют команду в монитор по поддерживаемому каналу `DDC/CI`.

## 2.2. Что это значит practically для текущего проекта

В текущем проекте путь данных такой:

- `ESP32-C6` отправляет телеметрию в `pc-app`;
- `pc-app` рассчитывает целевую яркость;
- `pc-app` меняет яркость монитора через `WMI` или `DDC/CI`.

Никакой прямой `I2C`-шины между `ESP32-C6` и монитором в текущей реализации нет.

## 2.3. Как проверить поддержку управления яркостью по `DDC/CI`

Перед тем как рассчитывать на `DDC/CI`, проверяйте монитор в такой последовательности:

1. Монитор должен быть внешним, а не встроенной матрицей ноутбука.
2. В экранном меню монитора желательно найти настройку вроде `DDC/CI = On`.
3. Монитор должен быть подключён по интерфейсу и через кабель, где `DDC/CI` реально проходит.
4. Windows API должен суметь обнаружить physical monitor.
5. Должен успешно отработать хотя бы один из вызовов:
   - `GetMonitorBrightness(...)`
   - `SetMonitorBrightness(...)`

Для этого проекта практический критерий поддержки такой:

- если монитор находится через `DdcMonitor.Discover()`, это ещё не гарантия полной поддержки;
- если `GetMonitorBrightness(...)` или `SetMonitorBrightness(...)` стабильно возвращают успех, монитор можно считать пригодным для `DDC/CI`-управления;
- если оба вызова не работают, монитор нужно считать неподдерживаемым для этого способа.

## 2.4. Как ведёт себя текущая реализация

Текущая реализация уже делает разумную проверку:

- сначала пытается обнаружить monitors через `WMI` и `DDC/CI`;
- для `DDC/CI` на запись пробует прочитать диапазон яркости;
- если диапазон прочитать не удалось, всё равно пробует `SetMonitorBrightness(...)` с процентом `0..100`;
- если запись не проходит, монитор помечается как проблемный.

Это полезно, потому что некоторые мониторы плохо отвечают на чтение, но принимают запись.

## 2.5. Как practically считать монитор поддерживаемым

Для текущего проекта монитор practically можно считать:

- `supported`:
  - обнаружился как физический монитор;
  - хотя бы одна тестовая установка яркости прошла успешно.
- `partially_supported`:
  - чтение текущей яркости не работает;
  - запись работает.
- `unsupported`:
  - монитор не обнаруживается как управляемый;
  - или запись яркости завершается ошибкой.

## 2.6. Какой порядок действий должен быть в приложении

Правильный порядок выглядит так:

1. обнаружить кандидатов на управление яркостью;
2. разделить встроенные дисплеи (`WMI`) и внешние (`DDC/CI`);
3. для каждого монитора проверить практическую возможность чтения/записи;
4. только после этого включать автоматическое применение brightness updates;
5. при повторяющихся ошибках отключать конкретный монитор, а не ломать весь sensor pipeline.

Именно такой подход лучше всего переживает частично совместимые мониторы.

## Смежные документы

- [protocol.md](./protocol.md) - текущий wire contract
- [firmware.md](./firmware.md) - текущая прошивка `ESP32-C6`
- [build.md](./build.md) - запуск Windows-приложения

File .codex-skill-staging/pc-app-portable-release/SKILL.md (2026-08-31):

---
name: pc-app-portable-release
description: Build the versioned LumaBloom Windows portable zip, first running every firmware project's own merged-binary build script and then bundling all matching firmware artifacts with the app and flashing tool. Use for standalone PC packages or full portable release artifacts.
---

# PC App Portable Release

Build the Windows portable release artifact for `pc-app/` using the flow documented in `docs/build-and-run.md`, then package it into the repo's expected versioned zip format.

## Workflow

1. By default, resolve the target version from the same MinVer configuration used by `pc-app`. Pass `--tag` only for an explicit release-version override.
2. From the repo root, run `.codex-skill-staging/pc-app-portable-release/scripts/build_portable_zip.py`. It discovers every directory under `firmware/`, requires its own `build_merged.py`, and runs every script with the resolved version before publishing the PC app.
3. Treat the direct `dotnet publish` single-file command as the lower-level equivalent documented in `docs/build-and-run.md`.
4. Report:
   - the publish output folder
   - the final zip path
   - the exact release filename
   - whether `Tools/esptool.exe` was bundled
   - every firmware artifact bundled into `Firmware/`
5. Treat this release build as strict:
   - the published `BrightnessSensor.ConsoleApp.exe` must report the exact requested tag, not a `preview` or other prerelease suffix
   - every firmware project must contribute artifacts and manifests matching the resolved version; never fall back to an older file or omit a project
6. If `dotnet publish` is blocked by sandbox access to `NuGet.Config` or package caches, rerun with escalation.

## Commands

### Build the versioned portable zip

```powershell
python .codex-skill-staging/pc-app-portable-release/scripts/build_portable_zip.py
```

### Build the single-file publish output directly

```powershell
dotnet publish pc-app/BrightnessSensor.ConsoleApp/BrightnessSensor.ConsoleApp.csproj `
  -c Release `
  -r win-x64 `
  --self-contained true `
  -o pc-app/artifacts/single-file/win-x64 `
  /p:PublishSingleFile=true `
  /p:IncludeNativeLibrariesForSelfExtract=true `
  /p:EnableCompressionInSingleFile=true `
  /p:DebugType=None `
  /p:DebugSymbols=false
```
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

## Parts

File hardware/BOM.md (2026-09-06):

# Bill Of Materials

## ESP32-C6 Build

| Qty | Part | Notes |
|-----|---|---|
| 1 | Waveshare ESP32-C6-LCD-1.47 | Target board for the ESP-IDF firmware |
| 1 | KY-018 light sensor module | Analog output is used |
| 3+  | Dupont jumper wires, 20 cm | `VCC`, `GND`, and `AO` |
| 1 | Breadboard or safe mounting base | Optional, but useful for prototyping |
| 1 | USB cable | Data-capable cable for flashing and serial telemetry |

## ESP32-C3 Super Mini Build

| Qty | Part | Notes |
|-----|---|---|
| 1 | ESP32-C3 Super Mini | USB must expose built-in USB Serial/JTAG |
| 1 | KY-018 light sensor module | Analog output connects to GPIO4 |
| 3+  | Dupont jumper wires, 20 cm | `VCC`, `GND`, and `AO` |
| 1 | Breadboard or safe mounting base | Optional, but useful for prototyping |
| 1 | USB data cable | Used for flashing, power, and serial telemetry |

The ESP32-C3 build uses the same flower, KY-018 holder, stem, joints, petals, leaves, wiring, and fasteners as the ESP32-C6 build. Its board-specific lower pot assembly has not been modeled or published yet.

## Printable Flower Enclosure

| Qty | Part | Notes |
|---|---|---|
| 1 set | White printed parts | Print from `3d-print/enclosure/White parts.3mf` |
| 1 set | Green printed parts | Print from `3d-print/enclosure/Green parts.3mf` |
| 1 set | Light-brown printed parts | Print from `3d-print/enclosure/Light brown parts.3mf` |
| 1 set | Brown printed parts | Print from `3d-print/enclosure/Brown parts.3mf` |
| As needed | Heat-set threaded inserts | Installed into `BR-003-3D` and `BR-006-3D` |
| 2 | `M3x6` screws | Fasten `BR-003-3D` to `BR-006-3D` |
| 2 | `M2x5` screws | Fasten the `BR-014-3D` sensor lid to `BR-009-3D` |
| 2 | Board mounting screws | Mount the ESP32-C6 board to `BR-003-3D` diagonally |
| As needed | Printed `BR-011-3D` pins  | Used in the vase rim and bud / stem assembly |

The current color-grouped `.3mf` plates include the ESP32-C6 lower pot parts. The shared flower parts can also be reused for the ESP32-C3 build, but a complete C3 print set will require the future ESP32-C3 pot and board mount. The STEP sources and selected STL exports live in `3d-print/source/`.

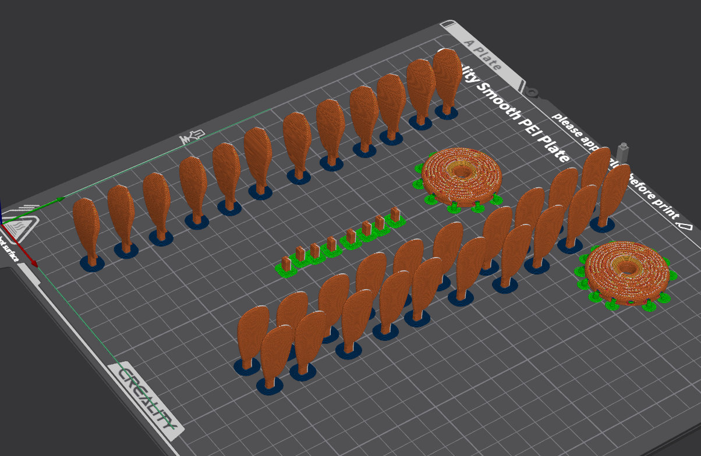
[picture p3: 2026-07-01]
hardware/3d-print/images/White parts.png

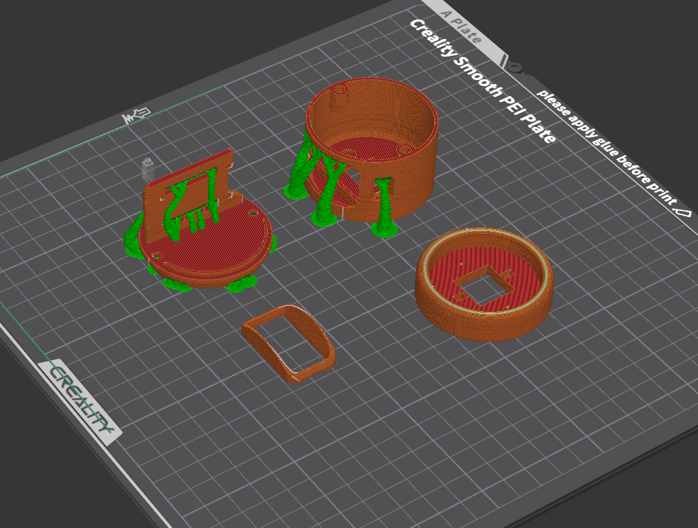
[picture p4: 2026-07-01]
hardware/3d-print/images/Light brown parts.png

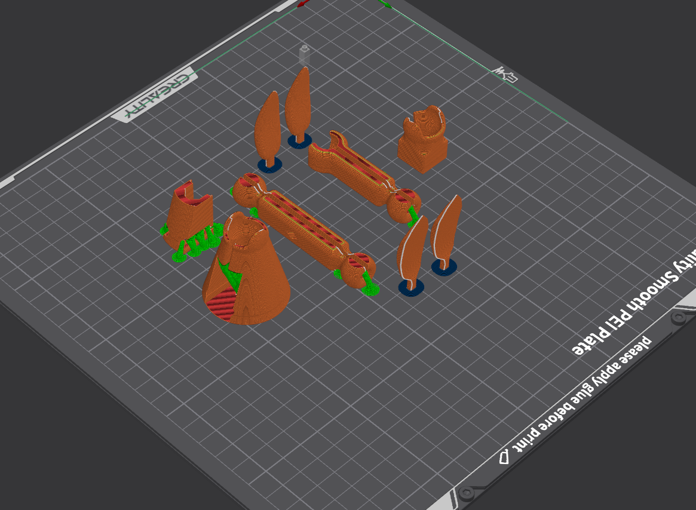
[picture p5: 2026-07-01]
hardware/3d-print/images/Green parts.png

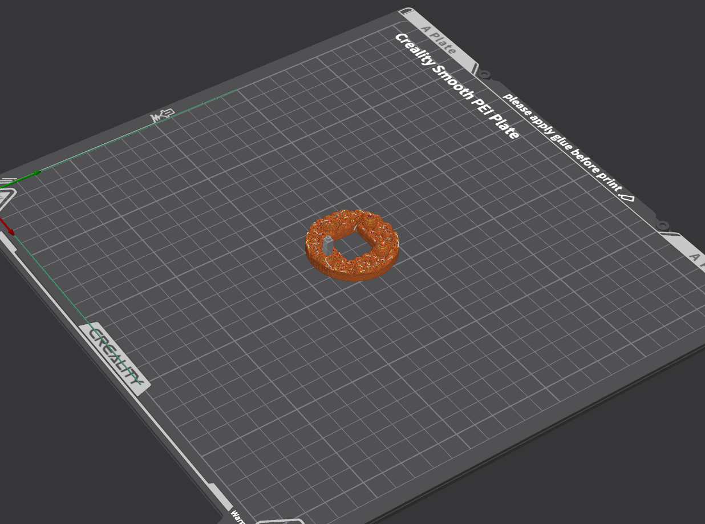
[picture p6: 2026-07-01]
hardware/3d-print/images/Brown parts.png

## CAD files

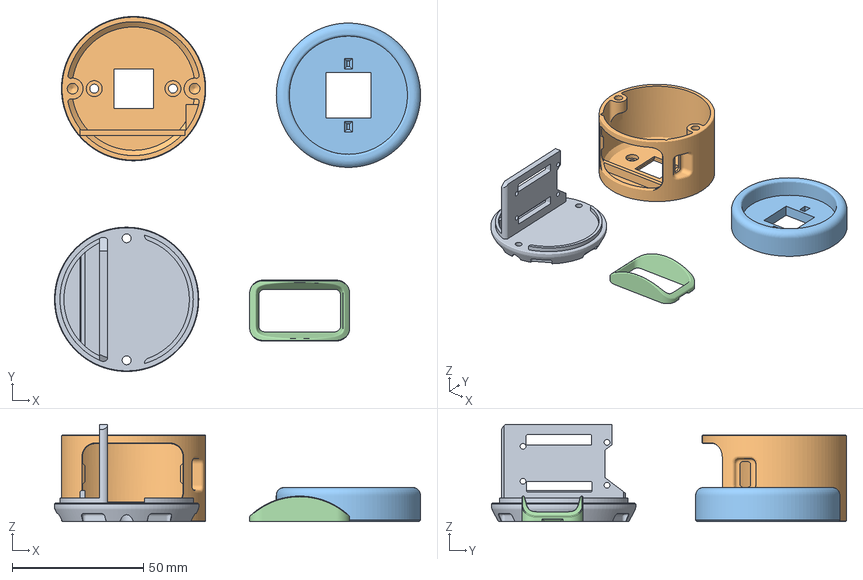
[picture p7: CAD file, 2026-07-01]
hardware/3d-print/enclosure/Light brown parts.3mf
139.5 x 135.3 x 37.0 mm
BR-003-3D - Bottom case.stl
BR-004-3D Wase.stl
BR-006-3D - Wase rim.stl
BR-005-3D - Display Frame.stl

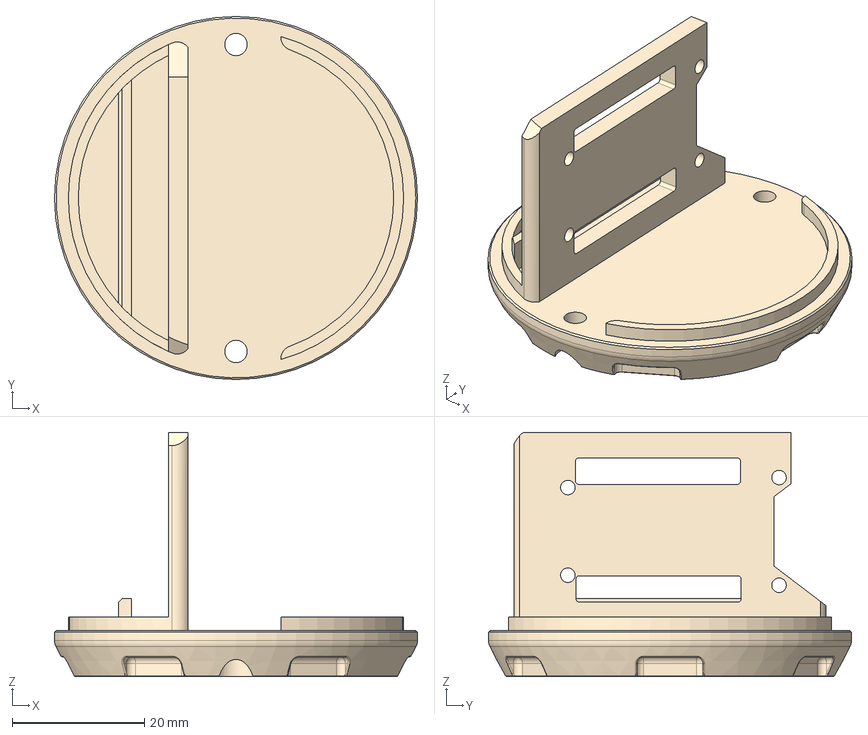
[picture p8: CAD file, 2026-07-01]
hardware/3d-print/source/BR-003-3D - Bottom case.step
55.0 x 55.0 x 37.0 mm

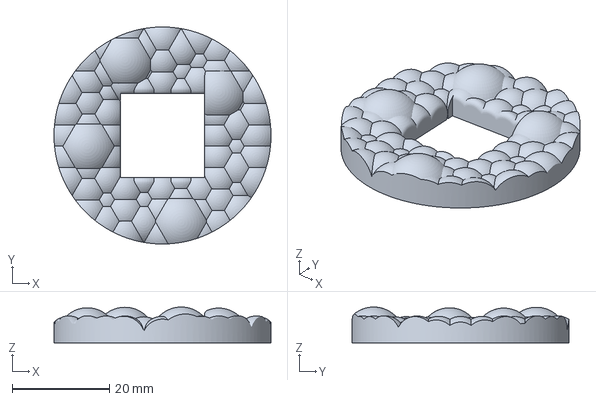
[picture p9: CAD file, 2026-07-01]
hardware/3d-print/enclosure/Brown parts.3mf
44.6 x 44.6 x 7.39 mm

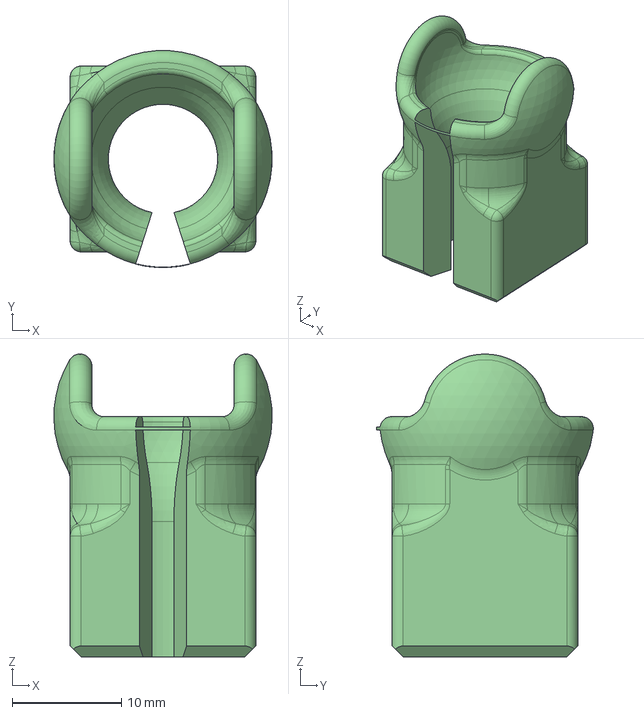
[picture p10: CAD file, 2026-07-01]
hardware/3d-print/source/BR-008-3D - Base Joint.step
19.9 x 19.8 x 27.7 mm

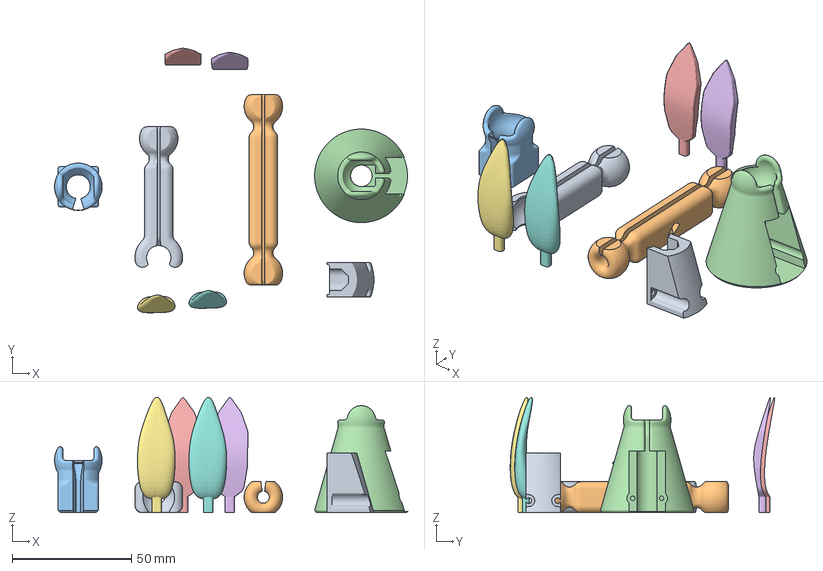
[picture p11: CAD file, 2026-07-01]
hardware/3d-print/enclosure/Green parts.3mf
148.3 x 111.1 x 48.5 mm
BR-001-3D - Ball joint.stl
BR-002-3D - Ball joint Mid.stl
BR-008-3D - Base Joint.stl
BR-009-3D - Bud.stl
BR-012-3D - Leaf.stl x 2
BR-013-3D Leaf V2.stl x 2
BR-014-3D - Sensor lid.stl

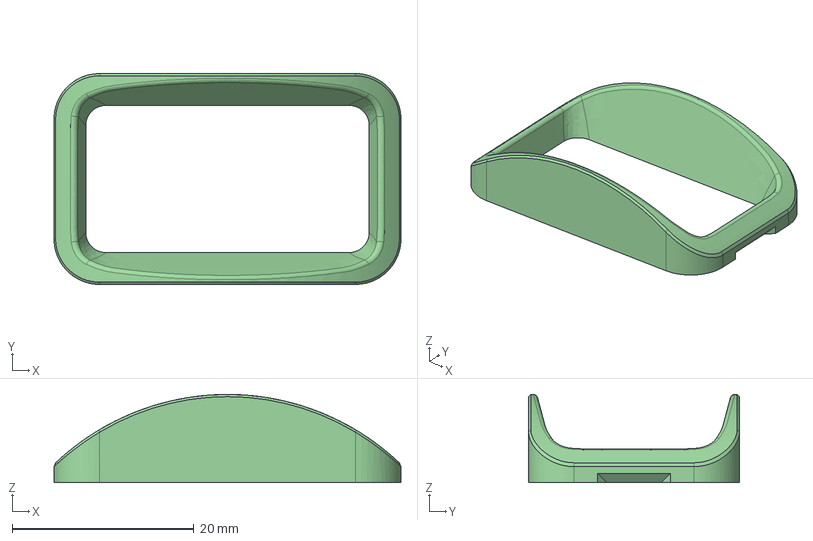
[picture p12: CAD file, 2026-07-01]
hardware/3d-print/source/BR-005-3D - Display Frame.step
38.1 x 23.2 x 9.70 mm

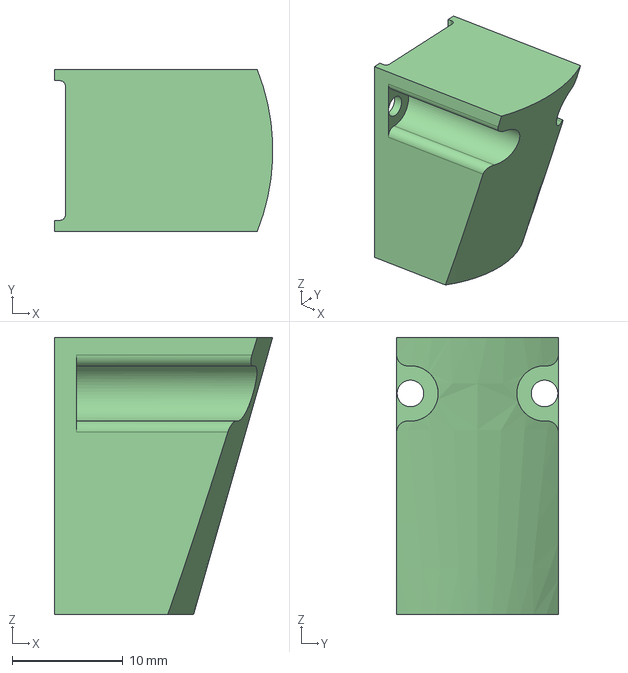
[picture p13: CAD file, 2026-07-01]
hardware/3d-print/source/BR-014-3D - Sensor lid.step
19.7 x 14.6 x 25.0 mm

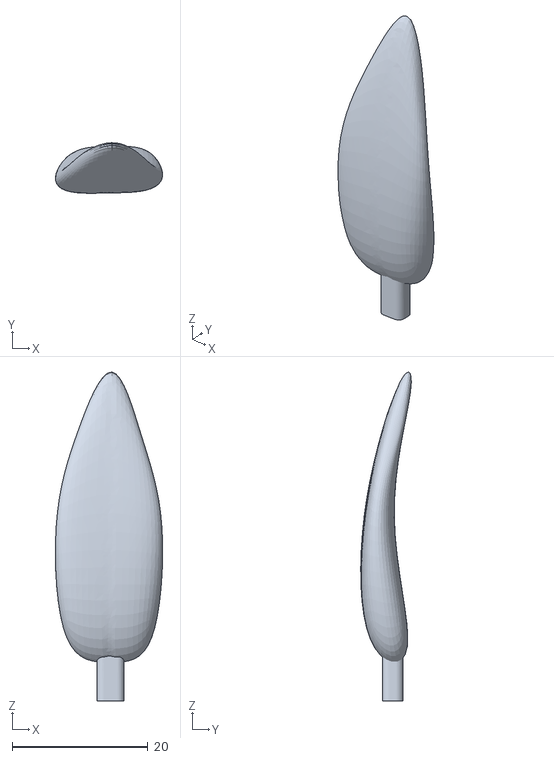
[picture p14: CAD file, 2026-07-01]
hardware/3d-print/source/BR-013-3D Leaf V2.stl
15.8 x 7.46 x 48.5

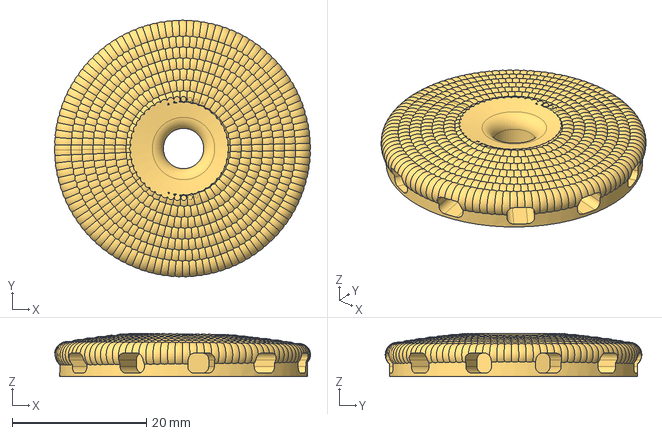
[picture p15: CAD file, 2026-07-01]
hardware/3d-print/source/BR-010-3D - Flower disk.step
38.1 x 38.2 x 6.42 mm

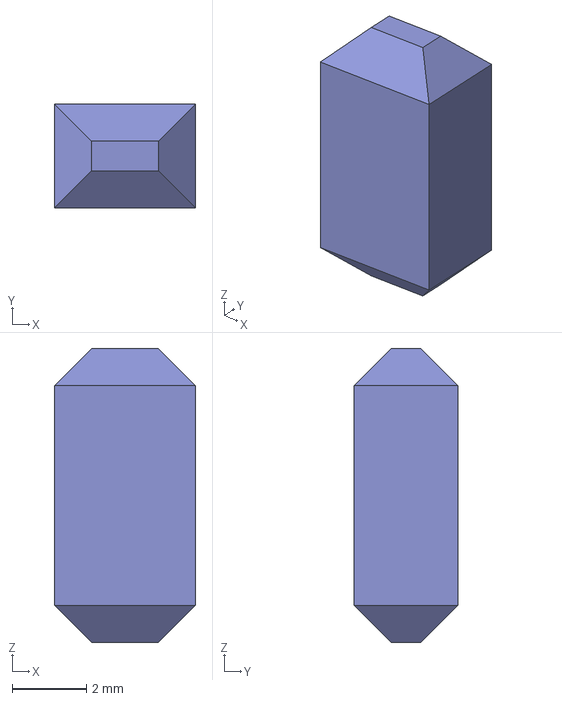
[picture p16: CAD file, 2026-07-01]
hardware/3d-print/source/BR-011-3D - Shaft.step
3.80 x 2.80 x 7.90 mm

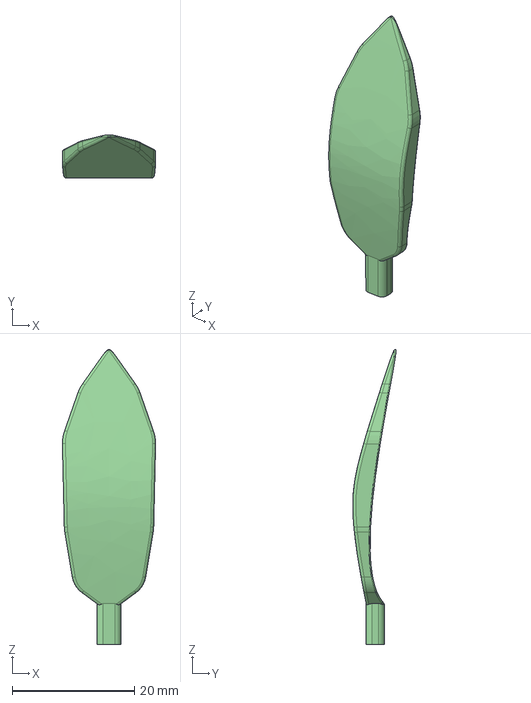
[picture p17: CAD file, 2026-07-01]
hardware/3d-print/source/BR-013-3D - Leaf.step
15.3 x 7.13 x 48.4 mm

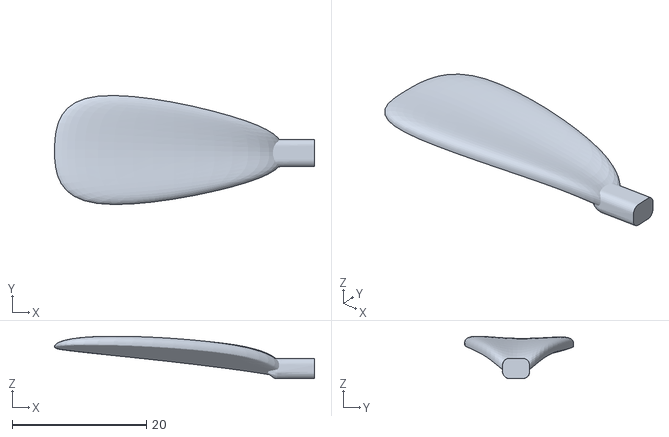
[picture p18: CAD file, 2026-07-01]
hardware/3d-print/source/BR-012-3D Petal V2.stl
38.7 x 16.2 x 6.33

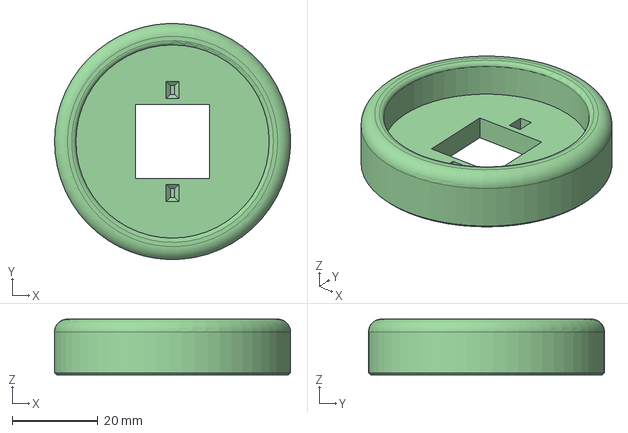
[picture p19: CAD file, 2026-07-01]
hardware/3d-print/source/BR-006-3D - Wase rim.step
55.0 x 55.0 x 13.0 mm

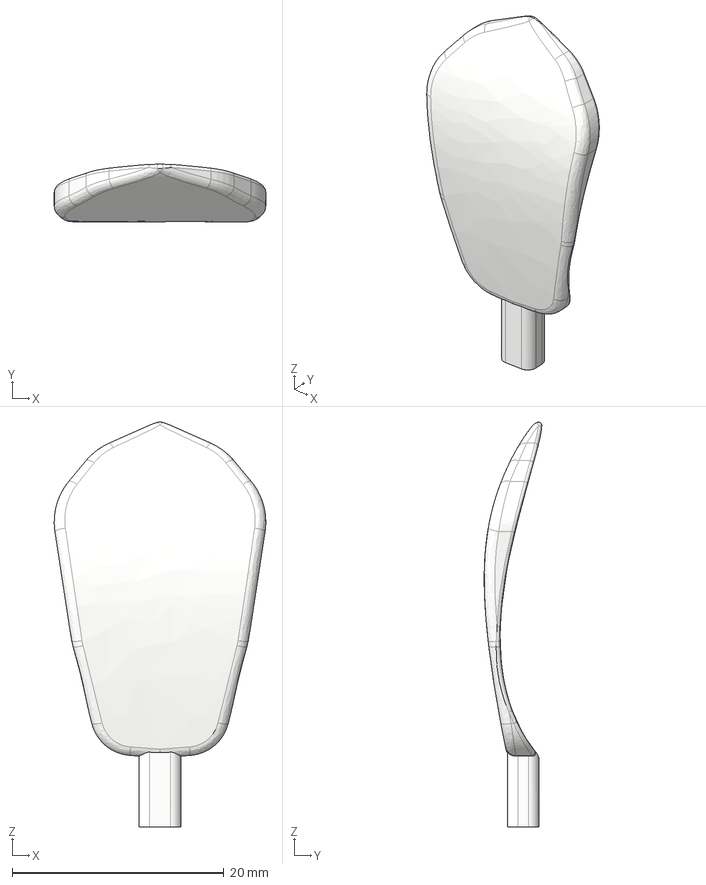
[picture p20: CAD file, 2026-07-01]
hardware/3d-print/source/BR-012-3D - Petal.step
20.0 x 5.45 x 38.3 mm

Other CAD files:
hardware/3d-print/source/BR-007-3D - Ground.step
hardware/3d-print/source/BR-009-3D - Bud.step
hardware/3d-print/source/BR-010-3D - Flower disk V2.step
hardware/3d-print/source/BR-004-3D Wase.step
hardware/3d-print/source/BR-001-3D - Ball joint.step
hardware/3d-print/source/BR-002-3D - Ball joint Mid.step

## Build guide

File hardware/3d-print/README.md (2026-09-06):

# Enclosure 3D Printing

This directory contains the shared printable flower body and the current ESP32-C6 lower pot assembly for LumaBloom sensor builds.

## Layout

| Path | Purpose |
| --- | --- |
| `enclosure/` | Slicer-ready `.3mf` plates grouped by filament color |
| `images/` | Preview and per-color reference images |
| `source/` | STEP source models and selected exported STL parts |
| `LICENSE.md` | License notes for physical-design assets |

## Print Files

The slicer-ready files are grouped by color:

| File | Suggested material / color | Reference image |
| --- | --- | --- |
| `enclosure/White parts.3mf` | White / petal parts | `images/White parts.png` |
| `enclosure/Green parts.3mf` | Green / stem and leaf parts | `images/Green parts.png` |
| `enclosure/Light brown parts.3mf` | Light brown / pot body parts | `images/Light brown parts.png` |
| `enclosure/Brown parts.3mf` | Brown / soil or accent parts | `images/Brown parts.png` |

Open each `.3mf` in your slicer, review bed placement and support settings, then slice with settings appropriate for your printer and filament.

## Source Models

The `source/` directory contains the full assembly and individual part sources:

| File | Purpose |
| --- | --- |
| `BR-000-AS - Fully assembly.step` | Full mechanical assembly |
| `BR-001-3D - Ball joint.step` | Ball joint |
| `BR-002-3D - Ball joint Mid.step` | Middle ball-joint segment |
| `BR-003-3D - Bottom case.step` | Bottom case |
| `BR-004-3D Wase.step` | Vase / pot body |
| `BR-005-3D - Display Frame.step` | Display frame |
| `BR-006-3D - Wase rim.step` | Vase / pot rim |
| `BR-007-3D - Ground.step` | Ground / soil insert |
| `BR-008-3D - Base Joint.step` | Base joint |
| `BR-009-3D - Bud.step` | Flower center / bud |
| `BR-010-3D - Flower disk.step` | Flower disk, original version |
| `BR-010-3D - Flower disk V2.step` | Flower disk, V2 |
| `BR-011-3D - Shaft.step` | Stem shaft |
| `BR-012-3D - Petal.step` | Petal source model |
| `BR-012-3D Petal V2.stl` | Petal V2 printable/exported mesh |
| `BR-013-3D - Leaf.step` | Leaf source model |
| `BR-013-3D Leaf V2.stl` | Leaf V2 printable/exported mesh |
| `BR-014-3D - Sensor lid.step` | Sensor lid |

## Assembly Notes

- The flower, KY-018 holder, stem, joints, petals, and leaves are shared by the ESP32-C6 and ESP32-C3 builds.
- The current lower pot, display opening, and board mount are for the Waveshare `ESP32-C6-LCD-1.47` build.
- A different lower pot and board mount are required for ESP32-C3 Super Mini and are not yet included.
- Print the color-grouped `.3mf` files before final wiring so the display, sensor, and cable routing can be checked against the case.
- Keep the KY-018 light path unobstructed after installing `BR-014-3D`.
- Route USB and sensor wiring so the ball joints can move without pulling on solder joints or Dupont connectors.
- Follow the full assembly order in `../ASSEMBLY.md`.
- The `.3mf` plates are the preferred print entry point. Use the STEP and STL files only when modifying or exporting replacement parts.

## Images

- `images/Assembled.jpg` - assembled physical device photo.
- `images/main.png` - complete product preview.
- `images/White parts.png` - white print plate reference.
- `images/Green parts.png` - green print plate reference.
- `images/Light brown parts.png` - light-brown print plate reference.
- `images/Brown parts.png` - brown print plate reference.

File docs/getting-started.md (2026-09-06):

# Getting Started

This guide gets one supported LumaBloom ESP32 device running with the Windows companion app.

## Requirements

- Windows 10/11.
- .NET SDK 10.0+.
- ESP-IDF 6.x.
- Waveshare `ESP32-C6-LCD-1.47` or an ESP32-C3 Super Mini with built-in USB Serial/JTAG.
- KY-018 analog light sensor.
- USB data cable.

For enclosure parts, wiring, BOM, and assembly, see [`../hardware/README.md`](../hardware/README.md).

## 1. Flash The Device

Choose the project for your board:

- ESP32-C6 with LCD: [`firmware/firmware_esp32c6/`](../firmware/firmware_esp32c6/)
- ESP32-C3 Super Mini without display: [`firmware/firmware_esp32c3_supermini/`](../firmware/firmware_esp32c3_supermini/)

Detailed commands are in [`firmware.md`](firmware.md).

The packaged Windows app can also flash bundled firmware. Open `Update`, switch to the `Device firmware` inner tab, select the required firmware version from the `.bin` files included in the package's `Firmware` folder, then select the target port. Each selectable binary must have a valid `<binary>.manifest.json`; the app currently supports `esptool` manifests. The firmware-port dropdown selects the automatically detected LumaBloom port by default; open it to rescan all current COM ports and choose another port when needed. Windows device descriptions help distinguish Bluetooth, USB serial, and Espressif/ESP32 ports. Manual firmware and port selections are temporary and do not change the port used for normal telemetry discovery.

## 2. Wire The Sensor

Default KY-018 wiring:

| KY-018 | ESP32-C6 LCD | ESP32-C3 Super Mini |
| --- | --- | --- |
| `VCC` | `3V3` | `3V3` |
| `GND` | `GND` | `GND` |
| `AO` / `S` | `GPIO4` | `GPIO4` (`ADC1_CH4`) |

Full wiring notes are in [`../hardware/WIRING.md`](../hardware/WIRING.md).

## 3. Configure The Windows App

Create `pc-app/appsettings.json` from the full analog example:

```powershell
Copy-Item pc-app/appsettings.esp32c6.example.json pc-app/appsettings.json
```

Useful config notes:

- `processing.adcMin=200`, `processing.adcMax=3200`, and `processing.invert=true` match the ESP32-C6 baseline and are a starting point for ESP32-C3; tune them from actual bright and dark readings
- `brightness.curve` accepts the main response points as `{ "lightPercent", "brightnessPercent" }`
- `ui.language` accepts `auto`, `en`, `ru`, or `es`

## 4. Run The App

From `pc-app/`:

```powershell
dotnet restore
dotnet run
```

On startup, the app probes available COM ports for the first valid LumaBloom telemetry stream, accepts the first port that emits `{"id":"lumabloom","ts":...,"raw":...}`, and starts applying brightness from the resolved app settings and response curve.

Firmware flashing remains available from `Update` while the app is waiting for valid telemetry, provided Windows exposes the target COM port and the package contains both `Tools/esptool.exe` and a bundled firmware file.

## Expected Result

- On ESP32-C6, the LCD shows the current ambient percentage; ESP32-C3 intentionally has no display.
- The app receives JSON lines with `id`, `ts`, and `raw`.
- Monitor brightness follows the configured brightness curve.

## Next Steps

- Tune brightness behavior in the app settings UI.
- In `Settings -> Response`, you can either edit the main `0/25/50/75/100` curve points directly or use the `Current light` action to say "for the light level right now, I want brightness X%".
- The `Current light` action reads the live sensor value, converts it with the active `adcMin`, `adcMax`, and `invert` settings, rebuilds the whole response curve around that anchor, and saves it immediately.
- The saved curve may contain an extra anchor point such as `16 -> 60` in addition to the usual five visible control points. This is expected and makes the chosen current-light target exact instead of approximate.
- Review [`docs/protocol.md`](protocol.md) when changing telemetry.
- Review [`docs/device-profiles.md`](device-profiles.md) when changing runtime defaults or the single-device settings model.

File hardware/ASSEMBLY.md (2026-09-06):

# Assembly

The upper flower assembly is shared by the Waveshare `ESP32-C6-LCD-1.47` and ESP32-C3 Super Mini builds. The checked-in lower pot assembly currently fits the ESP32-C6 board only. The ESP32-C3 Super Mini requires a different pot and board mount, which have not been modeled or published yet.

## Before You Start

- Flash the firmware track matching the selected board.
- Keep the USB cable disconnected while changing wiring or installing the board.
- Use `3V3` for the KY-018 power pin.
- Do not use `GPIO0` for the KY-018 signal on ESP32-C6; it can interfere with normal startup.
- Print the enclosure plates from `3d-print/enclosure/` before final assembly.

## Current Printed Parts

| Part | Source file |
| --- | --- |
| `BR-001-3D` | `3d-print/source/BR-001-3D - Ball joint.step` |
| `BR-002-3D` | `3d-print/source/BR-002-3D - Ball joint Mid.step` |
| `BR-003-3D` | `3d-print/source/BR-003-3D - Bottom case.step` |
| `BR-004-3D` | `3d-print/source/BR-004-3D Wase.step` |
| `BR-005-3D` | `3d-print/source/BR-005-3D - Display Frame.step` |
| `BR-006-3D` | `3d-print/source/BR-006-3D - Wase rim.step` |
| `BR-007-3D` | `3d-print/source/BR-007-3D - Ground.step` |
| `BR-008-3D` | `3d-print/source/BR-008-3D - Base Joint.step` |
| `BR-009-3D` | `3d-print/source/BR-009-3D - Bud.step` |
| `BR-011-3D` | `3d-print/source/BR-011-3D - Shaft.step` |
| `BR-014-3D` | `3d-print/source/BR-014-3D - Sensor lid.step` |

The KY-018 holder, bud, stem, joints, petals, and leaves above the pot are shared. The checked-in pot parts, display frame, and board mount form the ESP32-C6 lower assembly. Do not assume that any part of this lower assembly will be reused by the future ESP32-C3 pot.

## ESP32-C6 Complete Assembly

1. Flash the ESP32-C6 board with the firmware from `firmware/firmware_esp32c6/`.
2. Print the enclosure details from `3d-print/enclosure/`.
3. Heat-set the threaded inserts into `BR-003-3D`.
4. Heat-set the threaded inserts into `BR-006-3D`.
5. Insert the `BR-011-3D` pins into `BR-006-3D`, then insert the ground / soil part `BR-007-3D`.
6. Fasten `BR-003-3D` to `BR-006-3D` with two `M3x6` screws.
7. Take `BR-009-3D` and attach the second-version `BR-011-3D` shaft using two `BR-011-3D` pins.
8. Attach the ESP32-C6 board to `BR-003-3D` with two diagonal screws.
9. Connect the cable to the KY-018, insert the sensor into `BR-009-3D`, close it with the `BR-014-3D` sensor lid, and fasten the lid with two `M2x5` screws.
10. Pass the cable through the slotted hole in `BR-002-3D`, then connect `BR-002-3D` to `BR-009-3D` with the ball joint.
11. Pass the cable through the slotted hole in `BR-001-3D`, then connect it with ball joints to `BR-002-3D` and `BR-008-3D`.
12. Insert the assembled device stem into the top of the vase at `BR-006-3D`.
13. Connect the cables to the ESP32-C6 board.
14. Insert the assembled `BR-003-3D` part into `BR-004-3D`.
15. Insert the display frame `BR-005-3D` into `BR-004-3D`.
16. Done.

## ESP32-C3 Assembly Status

For ESP32-C3 Super Mini, assemble the KY-018 holder, bud, stem, joints, petals, and leaves using the same relevant steps and parts above. Use the ESP32-C3 wiring from `WIRING.md`.

Do not install the Super Mini into the current ESP32-C6 pot or assume the existing board mounting holes fit it. Final enclosure assembly remains pending until the ESP32-C3 lower pot and board-mounting model is added.

## Wiring Check

Default KY-018 wiring for both builds:

| KY-018 | Waveshare ESP32-C6-LCD-1.47 | ESP32-C3 Super Mini |
| --- | --- | --- |
| `VCC` / `+` | `3V3` | `3V3` |
| `GND` / `-` | `GND` | `GND` |
| `AO` / `S` | `GPIO4` (ADC) | `GPIO4` (`ADC1_CH4`) |

## Smoke Check

After enclosure assembly:

1. Connect the device over USB.
2. Start the Windows app from `pc-app/` so it can read live telemetry.
3. On ESP32-C6, confirm that the LCD shows a percentage and the diagnostics line updates with the live ADC reading. ESP32-C3 has no display.
4. Confirm that telemetry includes `raw`.

## Signal Quality

- Keep the analog signal wire short.
- Use a shared `GND` between the board and sensor.
- Avoid routing the signal wire near noisy USB hubs, power supplies, or display cables.
- Move the ball-joint / stem assembly through its expected range and confirm no wire is pulled tight.

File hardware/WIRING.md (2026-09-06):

# Wiring

## KY-018 -> Waveshare ESP32-C6-LCD-1.47

### Onboard LCD

The onboard LCD is already wired on the Waveshare board. The firmware uses these pins:

| LCD signal | ESP32-C6 GPIO |
| --- | --- |
| `MOSI` | `GPIO6` |
| `SCLK` | `GPIO7` |
| `LCD_CS` | `GPIO14` |
| `LCD_DC` | `GPIO15` |
| `LCD_RST` | `GPIO21` |
| `LCD_BL` | `GPIO22` |

Display controller: `ST7789`.

### Default KY-018 Pins

| KY-018 | Waveshare ESP32-C6-LCD-1.47 |
| --- | --- |
| `VCC` | `3V3` |
| `GND` | `GND` |
| `AO` / `S` | `GPIO4` (ADC) |

### Notes

- Only the analog output (`AO`) is used.
- If your KY-018 is connected to a different ADC pin, update `APP_KY018_ADC_CHANNEL` and the related `APP_KY018_ADC_GPIO` in `firmware/firmware_esp32c6/main/app_config.h`.
- For stable measurements, use a common `GND` and short wires.
- Using `GPIO0` for `KY-018` on ESP32-C6 is not recommended because it may interfere with normal board startup.

## KY-018 -> ESP32-C3 Super Mini

| KY-018 | ESP32-C3 Super Mini |
| --- | --- |
| `VCC` / `+` | `3V3` |
| `GND` / `-` | `GND` |
| `AO` / `S` | `GPIO4` (`ADC1_CH4`) |

### Notes

- This track targets Super Mini boards whose USB connector is wired to the ESP32-C3 built-in USB Serial/JTAG controller.
- Keep GPIO18 and GPIO19 free because they carry USB D- and D+.
- Power the KY-018 from `3V3`, not `5V`.
- Only the analog output is used; the firmware sends its native 12-bit ADC result.
- The upper flower and sensor-holder parts are shared with the ESP32-C6 enclosure. The ESP32-C3 Super Mini requires a different lower pot and board mount, which have not been modeled or published yet.

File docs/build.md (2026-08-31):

# Build

This document covers the Windows companion app.

## Requirements

- Windows 10/11.
- .NET SDK 10.0+.

## Restore, Build, Test

From `pc-app/`:

```powershell
dotnet restore
dotnet build brightness-sensor.sln
dotnet test brightness-sensor.sln
```

`BrightnessSensor.ConsoleApp` versioning is resolved from git tags during build via `MinVer`. A tagged commit such as `1.4.0` produces that exact app version; branch builds between tags produce a prerelease version automatically.

## Run

From `pc-app/`:

```powershell
dotnet run
```

The app opens a live terminal dashboard, discovers the ESP32-C6 serial device, reads raw telemetry, and applies monitor brightness through Windows APIs.

For detailed notes on how sensor values are read over `USB` and how monitor brightness is applied through `DDC/CI`, see [`sensor-transports-and-monitor-ddc.md`](sensor-transports-and-monitor-ddc.md).

## Portable Zip

From the repository root:

```powershell
python .codex-skill-staging/pc-app-portable-release/scripts/build_portable_zip.py
```

For a truly portable firmware-update bundle, place the official standalone Windows `esptool.exe` at:

```text
third_party/esptool/win-x64/esptool.exe
```

The portable zip script copies that file into `Tools/esptool.exe` beside the app. If the repo-local standalone binary is missing, the script skips bundling `esptool.exe` so the packaging problem is visible immediately instead of silently depending on a developer machine.

## Single-File Windows Publish

From the repository root:

```powershell
dotnet publish pc-app/BrightnessSensor.ConsoleApp/BrightnessSensor.ConsoleApp.csproj `
  -c Release `
  -r win-x64 `
  --self-contained true `
  -o pc-app/artifacts/single-file/win-x64 `
  /p:PublishSingleFile=true `
  /p:IncludeNativeLibrariesForSelfExtract=true `
  /p:EnableCompressionInSingleFile=true `
  /p:DebugType=None `
  /p:DebugSymbols=false
```

Output:

```text
pc-app/artifacts/single-file/win-x64/BrightnessSensor.ConsoleApp.exe
```

The publish output does not include `appsettings.json`. On first run without an explicit config path, the app creates a minimal config beside the executable and persists UI settings there.

The in-app application update flow also preserves an existing `appsettings.json` in the installed app folder, so user settings survive portable-package upgrades.

Before publishing, the portable release script discovers every immediate project under `firmware/` and runs its required project-local `build_merged.py`. Each project owns its toolchain and must emit all supported variants as `build/release/*_<tag>_merged.bin` with a `<binary>.manifest.json` sidecar. Old outputs for the target version are removed first. The portable package copies every matching artifact and manifest into `Firmware/`; the in-app Update screen lists entries whose manifest declares a supported flashing method.

The Update screen selects the automatically discovered LumaBloom COM port by default. Its firmware-port dropdown rescans `SerialPort.GetPortNames()` every time it opens, so the user can select a newly connected or alternative port without restarting the app. Entries include the Windows device name when available; native Espressif USB devices are marked `Espressif/ESP32`, and the validated telemetry port is marked as the automatic LumaBloom choice. Firmware version and port selections apply only to the current app session and are not persisted to `appsettings.json`.

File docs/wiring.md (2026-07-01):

# Wiring

Hardware wiring documentation now lives in [`../hardware/WIRING.md`](../hardware/WIRING.md).

The full hardware section is indexed in [`../hardware/README.md`](../hardware/README.md).

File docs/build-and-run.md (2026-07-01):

# Build And Run

This document has been split into focused guides:

| Guide | Purpose |
| --- | --- |
| [`getting-started.md`](getting-started.md) | End-to-end setup |
| [`firmware.md`](firmware.md) | ESP32-C6 firmware build, flash, monitor, and release binary |
| [`build.md`](build.md) | Windows app restore, build, test, run, and publish |
| [`../CONTRIBUTING.md`](../CONTRIBUTING.md) | Contribution workflow and validation expectations |

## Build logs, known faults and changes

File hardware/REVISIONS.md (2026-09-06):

# Hardware Revisions

## Current Prototype

### ESP32-C6 + KY-018 + LCD

- Board: Waveshare `ESP32-C6-LCD-1.47`.
- Sensor: KY-018 analog light sensor.
- Default signal pin: `GPIO4`.
- Firmware track: ESP-IDF.
- Telemetry semantics: raw ADC value on the USB contract, with normalized percent kept local to the LCD/UI.
- Important constraint: avoid `GPIO0` for the sensor signal because it can affect normal startup.

### ESP32-C3 Super Mini + KY-018

- Board: ESP32-C3 Super Mini with built-in USB Serial/JTAG exposed on USB.
- Sensor: the same KY-018 analog light sensor used by the ESP32-C6 build.
- Default signal pin: `GPIO4` (`ADC1_CH4`).
- Firmware track: ESP-IDF, without a display task.
- Telemetry semantics: the same raw ADC value on the USB contract.
- Mechanical status: the flower above the pot is shared; the different ESP32-C3 lower pot and board mount are not yet available.

### LumaBloom Enclosure

- The upper flower assembly is shared between the ESP32-C6 and ESP32-C3 hardware tracks.
- The current lower pot and board mount target the Waveshare `ESP32-C6-LCD-1.47`.
- A different lower pot and board mount are planned for ESP32-C3 Super Mini but are not yet available.
- Printable plates: `White parts.3mf`, `Green parts.3mf`, `Light brown parts.3mf`, and `Brown parts.3mf`.
- Required assembly hardware includes heat-set threaded inserts, two `M3x6` screws, two `M2x5` screws, ESP32-C6 board mounting screws, and 20 cm Dupont jumper wires.
- Assembly uses `BR-003-3D` as the bottom case, `BR-004-3D` as the vase body, `BR-005-3D` as the display frame, `BR-006-3D` as the vase rim, `BR-009-3D` as the sensor bud, and `BR-014-3D` as the sensor lid.

## Change Log

| Revision | Date | Notes |
| --- | --- | --- |
| Prototype | 2026-07-01 | Initial hardware documentation split into `hardware/` with BOM, wiring, assembly, and a 3D-print asset structure. |
| LumaBloom enclosure assets | 2026-07-01 | Added color-grouped `.3mf` print plates, preview images, and STEP/STL source files for the flower enclosure. |
| C6 enclosure assembly | 2026-07-01 | Scoped enclosure assembly to the ESP32-C6 build, documented heat-set inserts, `M3x6` / `M2x5` screws, KY-018 installation, cable routing, and `BR-005-3D` display-frame insertion. |
| BOM cable length | 2026-07-01 | Set Dupont jumper wire length to 20 cm for the documented hardware builds. |
| C3 enclosure scope | 2026-09-07 | Documented the shared flower assembly and the missing board-specific ESP32-C3 lower pot and mount. |

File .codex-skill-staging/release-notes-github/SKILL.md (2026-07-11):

---
name: release-notes-github
description: Draft or update GitHub release notes for the LumaBloom release flow in this repository in a fixed English markdown format. Use when Codex needs to prepare a new release description and the request specifies both a source tag and a target tag, generate release links, or describe the expected versioned artifact names. Do not use this skill itself to build the firmware payload or Windows portable zip.
---

# Release Notes GitHub

Create release notes by reusing the repo's established structure instead of inventing a new format. The final release text should be in English.

## Workflow

1. Start from `references/release-template.md`.
2. Require the user request or the working prompt to include both tags:
   - source tag: from which previous release the changes are described
   - target tag: for which new release the text and links are produced
3. Confirm current firmware behavior against source docs before copying technical claims:
   - `firmware/firmware_esp32c6/README.md`
   - `README.md`
   - `docs/build-and-run.md`
4. If the user gives new artifact names, tags, or links, update them everywhere consistently.
5. Write the final release description in English.

## Required Output Shape

Keep this section order unless the user asks otherwise:

1. `## Included In This Release`
2. `## Release Files`
3. `## What Changed`
4. `## Supported Hardware`
5. `## How To Flash`
6. `## Telemetry`

Use short bullet lists and fenced code blocks where the template already uses them.

## Tag And Artifact Rules

- Always state both tags in the working context: `from <old-tag> to <new-tag>`.
- Replace the old tag in all release asset links with the target tag.
- Keep firmware links in the form:
  `https://github.com/mkdsfm/LumaBloom/releases/download/<tag>/<filename>`
- Include the target version in the Windows portable release filename.
- Prefer this filename form:
  - `luma-bloom-pc-app_<to-tag>_win-x64-portable.zip`
- If the release includes the Windows portable app, describe that it contains the bundled firmware release folder and `Tools/esptool.exe` for the Update flow.
- If the user gives only filenames and no URLs, infer the URL from the tag and repository release pattern above.
- For the `## What Changed` section, describe the delta from the source tag to the target tag rather than writing a generic summary.

## Artifact References

- Use these expected filenames in the release note when artifacts are part of the release:
  - `luma-bloom-pc-app_<to-tag>_win-x64-portable.zip`
- If the user asks to actually build those artifacts, delegate that work to:
  - `.codex-skill-staging/esp32-release-flash`
  - `.codex-skill-staging/pc-app-portable-release`

## Technical Accuracy Rules

- Do not blindly copy telemetry semantics from an older release note.
- If repo docs say `value` is normalized or calibration is required, surface that instead of repeating an older raw-ADC claim.
- Preserve hardware wiring exactly when it is unchanged:
  - `VCC -> 3V3`
  - `GND -> GND`
  - `AO -> GPIO4`
- Keep the warning about avoiding `GPIO0` on `ESP32-C6` when it still matches the docs.

## Resources

- For the reusable release-note skeleton with placeholders, read `references/release-template.md`.

## Default Behavior

If the user asks to "write release notes" without more detail:

1. Start from the template in `references/release-template.md`.
2. Ask for the missing tag range if either the source tag or the target tag is absent.
3. Ask for missing artifact names only if they cannot be inferred safely.

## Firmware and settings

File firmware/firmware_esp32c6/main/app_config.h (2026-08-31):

#pragma once

#include "driver/gpio.h"
#include "driver/spi_common.h"
#include "esp_adc/adc_oneshot.h"

#define APP_PROTOCOL_ID "lumabloom"
//select board 
#define APP_DISPLAY_ST7789 1
#define APP_DISPLAY_JD9853 2

#ifndef APP_DISPLAY_TYPE
#define APP_DISPLAY_TYPE APP_DISPLAY_ST7789
#endif

// Sensor reads stay at 200 ms. The display task ticks more often so it can
// advance the animation independently between sensor readings.
#define APP_READ_INTERVAL_MS 200
#define APP_DISPLAY_INTERVAL_MS 50

// User-facing animation tuning:
// - lower FRAME_INTERVAL for faster flower transitions;
// - increase HYSTERESIS if the flower flickers near a frame boundary.
#define APP_ANIMATION_FRAME_INTERVAL_MS 150
#define APP_ANIMATION_HYSTERESIS_PERCENT 2

#define APP_KY018_ADC_UNIT ADC_UNIT_1
#define APP_KY018_ADC_CHANNEL ADC_CHANNEL_4
#define APP_KY018_ADC_GPIO GPIO_NUM_4
#define APP_KY018_ADC_MIN 200
#define APP_KY018_ADC_MAX 3200
#define APP_KY018_INVERT 1
#define APP_KY018_GAMMA 2.0f

#define APP_LCD_HOST SPI2_HOST
#define APP_LCD_PIXEL_CLOCK_HZ (40 * 1000 * 1000)
#define APP_LCD_WIDTH 320
#define APP_LCD_HEIGHT 172
#define APP_LCD_BACKLIGHT_PERCENT 10
// These offsets select the visible 320x172 area inside the ST7789 memory.
// They are panel geometry settings, not UI element coordinates.

#if APP_DISPLAY_TYPE == APP_DISPLAY_ST7789
    #define APP_LCD_CONTROLLER_ST7789 1
    #define APP_LCD_PIXEL_CLOCK_HZ (40 * 1000 * 1000)
    #define APP_LCD_X_OFFSET 0
    #define APP_LCD_Y_OFFSET 34
    #define APP_LCD_SPI_MOSI GPIO_NUM_6
    #define APP_LCD_SPI_CLK GPIO_NUM_7
    #define APP_LCD_CS GPIO_NUM_14
    #define APP_LCD_DC GPIO_NUM_15
    #define APP_LCD_RST GPIO_NUM_21
    #define APP_LCD_BL GPIO_NUM_22

    #define APP_LCD_SWAP_XY true
    #define APP_LCD_MIRROR_X true
    #define APP_LCD_MIRROR_Y true
    #define APP_LCD_INVERT_COLOR true
    #define LCD_COLOR_TEXT 0x765F
    #define LCD_COLOR_TEXT_OUTLINE 0x2881
    #define LCD_COLOR_PROGRESS 0x765F

#elif APP_DISPLAY_TYPE == APP_DISPLAY_JD9853
    #define APP_LCD_CONTROLLER_JD9853 1
    #define APP_LCD_PIXEL_CLOCK_HZ (40 * 1000 * 1000)
    #define APP_LCD_X_OFFSET 0
    #define APP_LCD_Y_OFFSET 34
    #define APP_LCD_SPI_MOSI GPIO_NUM_2
    #define APP_LCD_SPI_CLK  GPIO_NUM_1
    #define APP_LCD_CS       GPIO_NUM_14
    #define APP_LCD_DC       GPIO_NUM_15
    #define APP_LCD_RST      GPIO_NUM_22
    #define APP_LCD_BL       GPIO_NUM_23

    #define APP_LCD_SWAP_XY true
    #define APP_LCD_MIRROR_X true
    #define APP_LCD_MIRROR_Y false
    #define APP_LCD_INVERT_COLOR false
    #define LCD_COLOR_TEXT 0xF731
    #define LCD_COLOR_TEXT_OUTLINE 0x2881
    #define LCD_COLOR_PROGRESS 0xF731

#else
    #error "Unsupported APP_DISPLAY_TYPE"

#endif

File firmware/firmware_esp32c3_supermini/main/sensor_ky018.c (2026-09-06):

#include "sensor_ky018.h"

#include "app_config.h"
#include "esp_check.h"
#include "esp_log.h"

static const char *TAG = "sensor_ky018";

esp_err_t sensor_ky018_init(sensor_ky018_t *sensor)
{
    ESP_RETURN_ON_FALSE(sensor != NULL, ESP_ERR_INVALID_ARG, TAG, "sensor pointer is null");

    if (sensor->initialized && sensor->adc_handle != NULL) {
        return ESP_OK;
    }

    if (sensor->adc_handle != NULL) {
        sensor->initialized = true;
        return ESP_OK;
    }

    const adc_oneshot_unit_init_cfg_t unit_config = {
        .unit_id = APP_KY018_ADC_UNIT,
        .ulp_mode = ADC_ULP_MODE_DISABLE,
    };

    adc_oneshot_unit_handle_t adc_handle = NULL;
    ESP_RETURN_ON_ERROR(adc_oneshot_new_unit(&unit_config, &adc_handle), TAG, "adc_oneshot_new_unit failed");

    const adc_oneshot_chan_cfg_t channel_config = {
        .atten = APP_KY018_ADC_ATTEN,
        .bitwidth = APP_KY018_ADC_BITWIDTH,
    };
    esp_err_t err = adc_oneshot_config_channel(adc_handle, APP_KY018_ADC_CHANNEL, &channel_config);
    if (err != ESP_OK) {
        adc_oneshot_del_unit(adc_handle);
        return err;
    }

    sensor->adc_handle = adc_handle;
    sensor->initialized = true;

    ESP_LOGI(TAG, "KY-018 ready on ADC unit %d, channel %d, gpio=%d",
             APP_KY018_ADC_UNIT,
             APP_KY018_ADC_CHANNEL,
             APP_KY018_ADC_GPIO);
    return ESP_OK;
}

esp_err_t sensor_ky018_read(sensor_ky018_t *sensor, device_reading_t *reading)
{
    ESP_RETURN_ON_FALSE(sensor != NULL, ESP_ERR_INVALID_ARG, TAG, "sensor pointer is null");
    ESP_RETURN_ON_FALSE(reading != NULL, ESP_ERR_INVALID_ARG, TAG, "reading pointer is null");
    ESP_RETURN_ON_FALSE(sensor->initialized, ESP_ERR_INVALID_STATE, TAG, "sensor is not initialized");
    ESP_RETURN_ON_FALSE(sensor->adc_handle != NULL, ESP_ERR_INVALID_STATE, TAG, "ADC handle is not initialized");

    reading->valid = false;

    int raw_adc = 0;
    ESP_RETURN_ON_ERROR(adc_oneshot_read(sensor->adc_handle, APP_KY018_ADC_CHANNEL, &raw_adc), TAG, "KY-018 read failed");

    reading->raw_adc = raw_adc;
    reading->valid = true;
    return ESP_OK;
}

esp_err_t sensor_ky018_deinit(sensor_ky018_t *sensor)
{
    ESP_RETURN_ON_FALSE(sensor != NULL, ESP_ERR_INVALID_ARG, TAG, "sensor pointer is null");

    adc_oneshot_unit_handle_t adc_handle = sensor->adc_handle;
    sensor->adc_handle = NULL;
    sensor->initialized = false;

    if (adc_handle == NULL) {
        return ESP_OK;
    }

    return adc_oneshot_del_unit(adc_handle);
}

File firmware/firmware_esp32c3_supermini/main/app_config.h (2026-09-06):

#pragma once

#include "driver/gpio.h"
#include "esp_adc/adc_oneshot.h"

#define APP_PROTOCOL_ID "lumabloom"
#define APP_READ_INTERVAL_MS 200

#define APP_KY018_ADC_UNIT ADC_UNIT_1
#define APP_KY018_ADC_CHANNEL ADC_CHANNEL_4
#define APP_KY018_ADC_GPIO GPIO_NUM_4
#define APP_KY018_ADC_BITWIDTH ADC_BITWIDTH_12
#define APP_KY018_ADC_ATTEN ADC_ATTEN_DB_12

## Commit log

2026-04-05 feat: автопоиск COM порта
2026-04-26 feat: прошивка для esp3c6 with lcd 1.47
2026-04-26 refactor: readmi для esp32c3
2026-05-28 feat: использование ky-018 вместо gy-302
2026-05-28 fix: переход с gpio0 на gpio4
    [app_config.h]
2026-05-29 Update KY-018 sensor wiring documentation to reflect GPIO4 change
2026-05-31 feat: убраны лишние параметры конфига
2026-06-26 refactor: инглиш лангуаге
2026-06-27 feat: Add ESP32-C6 runtime calibration and normalized 0..1000 telemetry
2026-06-28 fix: calibration
2026-06-30 feat: UI esp32c6
2026-07-01 Add ESP32-C6 hardware enclosure docs and assets
    [BR-001-3D - Ball joint.step, BR-002-3D - Ball joint Mid.step, BR-003-3D - Bottom case.step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]
2026-07-01 Refresh project documentation landing pages
2026-07-03 fix: auto calibration
2026-07-04 feat: calibration by current value
2026-07-07 feat: актуализация калибровки
2026-07-08 delete: clear auto calibrate
2026-07-08 Fix manual brightness without sensor telemetry
    Closes #10
2026-07-11 feature: adв auto upload app and firemwere
2026-07-12 Add ESP32-C6 animated LCD screen
2026-08-16 Add new board support and improve animation
2026-08-31 fix: inversion for ST7789
    [app_config.h]
2026-09-06 feat: firmware for esp32c3 super mini
